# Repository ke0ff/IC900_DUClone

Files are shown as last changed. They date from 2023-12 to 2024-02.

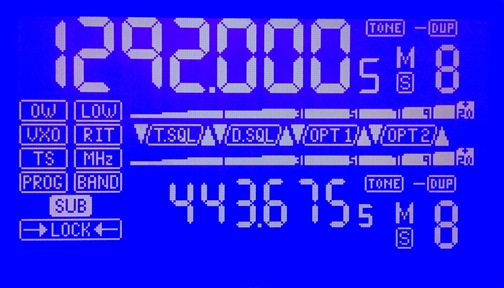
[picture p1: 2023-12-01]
Early_Mockup.JPG

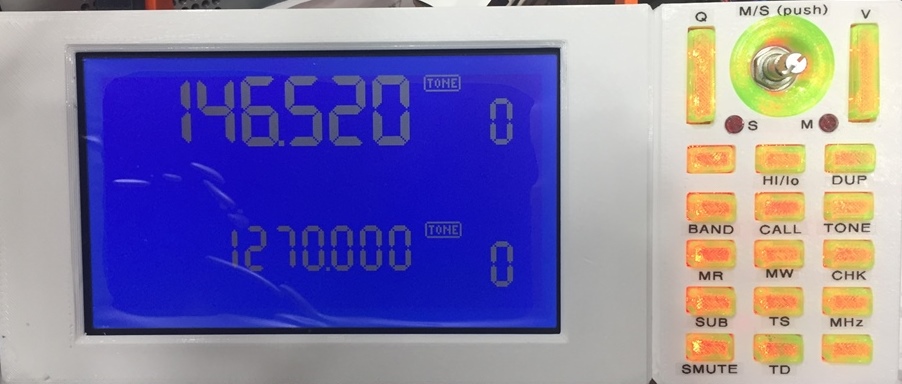
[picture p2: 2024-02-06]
Snapshots/FF900F_frontview.JPG

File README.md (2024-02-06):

# IC900_DUClone
Display clone to replace the LCD ICs/Glass of the original ICOM IC-900 controller

01/05/24<br>
Current state of SW: Initial IC-900-DUC converter DVT compete.  Declared fit for progress into hardware development.  Design is in C (baremetal).

Current state of HW: In FAB.  PCBs should be in-hand by mid-January, 2024.  Design is in Circuit Studio.  In total, there are 6 PCBs for the RDU clone and MFMIC option:<br>
- IC900-RDU (circa 2020): The original controller clone CCA, Tiva MCU
- IC900-DUC (new): The LCD controller and switch matrix CCA, Tiva MCU.  Also holds the NVRAM mod for the RDU and a power switch circuit
- IC900-DIAL (new): A small pcb that connects the dial encoder and dial back-light LEDs to the DUC CCA (no MCU)
- IC90x_RCU-B2 (circa 2020): The MFMIC CCA for the A-unit up/down de-mux function (ATTINY-816)
- IC900_ACONN (new): Provides connectors for RDU and host PC.  The MFMIC CCA mates to this PCB also.  A single 4-pr cable (CAT5) hard-connects to the IC-900 A-Unit
- HM-133B (circa 2020): This is the wired-remote version of the original HM-133 design.  It only supports the ICOM FM radio 8-pin circular/DIN format and provides a serial connection to the MFMIC/RDU to carry the button press messages back to the RDU controller

The "new" PCBs are contained here as complete data packages (source and FAB data).  The older PCBs are committed as FAB data only.

Electronics: Development prototype uses a Tiva TM4C123G Launchpad and Newhaven Display (Inc.) NHD-240128WG-ATMI-VZ# 240x128 graphics LCD.  Switches and backlighting for nomenclature follow a similar architecture as that of the original IC-900 controller. The final design features jumper-wire connections from the RDU Clone board mated to the DUC PCB.  The arrangement would theoretically support using an original IC900 RDU control board in place of the clone-RDU allowing the new LCD to interface with the original controller.

Mechanical: 3D model in advanced stages, nearing prototype readiness. Still need to work out 3D print strategies to support illuminated nomenclature.  Design is in OpenSCAD.  In-process STL files are now in repo.

The "Snapshots" folder contains some images of the current state of the development.

BOM cost: Current cost data is in the $300 per radio ball-park for components and PCBs (not including any costs associated with 3D printing or multiple freight costs associated with lost or forgotten parts - ACH!!!).

02/05/24<br>
First article is in DVT!!! The main mechanical deviation is that of button nomenclature.  I still don't have a difinitive solution in mind.  Cheesy, label printed lettering is the order of the day.  All else is progressing well, aiming for a first-to-field prototype by the end of the month.

Added UM folder for the user's manual source files.

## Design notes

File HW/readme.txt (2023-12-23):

Hardware design for the IC900 display clone interface
Joe Haas, KE0FF
Initial commit: 12/22/2023

Designs are in Altium Circuit Studio.

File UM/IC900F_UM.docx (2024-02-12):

IC900F Remote Controller User’s Manual

Joe Haas, KE0FF

02/11/24

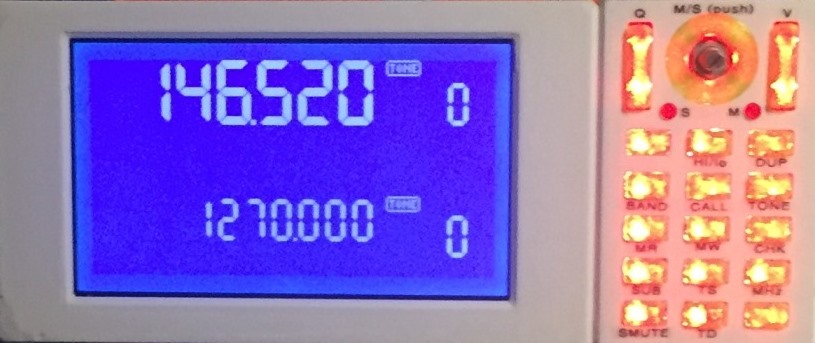
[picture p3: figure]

Introduction

This manual describes the operation of the IC900F, an alternate Remote Controller for the IC900 radio. The mechanical and electrical elements peculiar to the IC900F are also discussed, but for all other aspects of the IC900 radio system, the operator is referred to the IC-900A Instruction Manual, published by ICOM.

Contact information

The author/designer may be contacted at the following email address:

Joe Haas, KE0FF

email: joeh@ke0ff.org

web: www.ke0ff.org

github: https://www.github.com/ke0ff/

Forward

This project was born by an intersection of chance and whimsy to create an alternate controller for the IC-900. Mostly, it serves those who find themselves without such a controller, but in the process, a number of enhancements have been introduced which make the alternate device much more desirable than the original. While some measure of continuity from the original is maintained, new features have blurred that line considerably. Thus, the experienced IC-900 user may find that some considerable “re-learning” is needed to adapt to the new way of doing things.

Such change has not been undertaken lightly. I am a strong supporter of “better” but not so much do I support “newer”. Too many developers like to think that their brand of new is better than the previous version. While I am biased somewhat, I hope that you will agree that most of what I present here as “new” will also be welcomed as “better”.

One aspect that most all should agree is better is that this project is open-source. All of the electrical, software, and 3D models are available via my github repo. Not that that helps much, my source code often baffles even me after I’ve been away from it for a time, but it is the best I can manage given the skills and time I have – this is pursued as a hobby, not a business enterprise. You are free to modify any aspect of the design within the confines of the github license(s). I will assist as best I am able.

It should be noted that the IC-900 “OPT” modules (CTCSS squelch and DTMF coded squelch) are not currently supported. These may come in time, as user demand might influence. For now, they should not be installed.

Connections

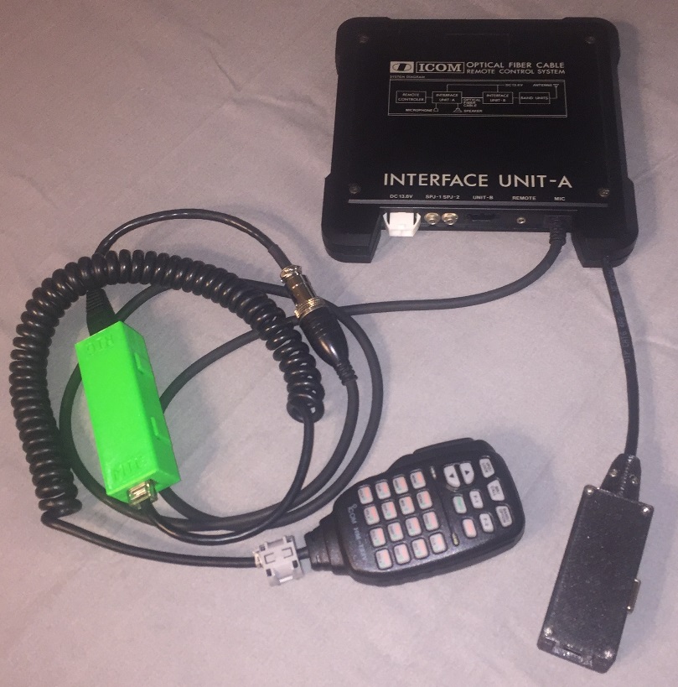
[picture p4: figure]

Figure 1: Modified IC-900 A-Unit and HM-133 Adapter (the controller connection unit is pictured in the lower right of the image)

In order to get the benefit of the HM-133 microphone features, the new controller requires that the A-unit be modified to facilitate the serial connection from the HM-133 to the controller. Figure 1 illustrates a modified A-unit for reference. The hardware to accomplish this also provides an RJ-45 connection for the remote unit. A standard Ethernet cable is recommended so that the signal pairing is correct. Note: The RDU RJ-45 connection is NOT compatible with the HM-133. Care must be exercised to avoid connecting the HM-133 to the RDU connection.

The HM-133 features an adapter cable that connects to the A-unit 8-pin circular connection for the system microphone. A standard, HM-14 (or equivalent) microphone can still be used in place of the HM-133. The connection is seamless and requires no special consideration from the operator.

The controller connection unit features the RJ-45 connection to the Remote Unit and also a 9-pin DSUB connector for a standard COM PORT connection to a PC (115.2 Kbaud, N81). This connection is used to save and restore memory settings for the radio (future enhancements will provide a custom program to perform real-time CAT control of the radio). This interface is describe later in this document.

All other connections are covered in the IC-900 documentation provided by ICOM.

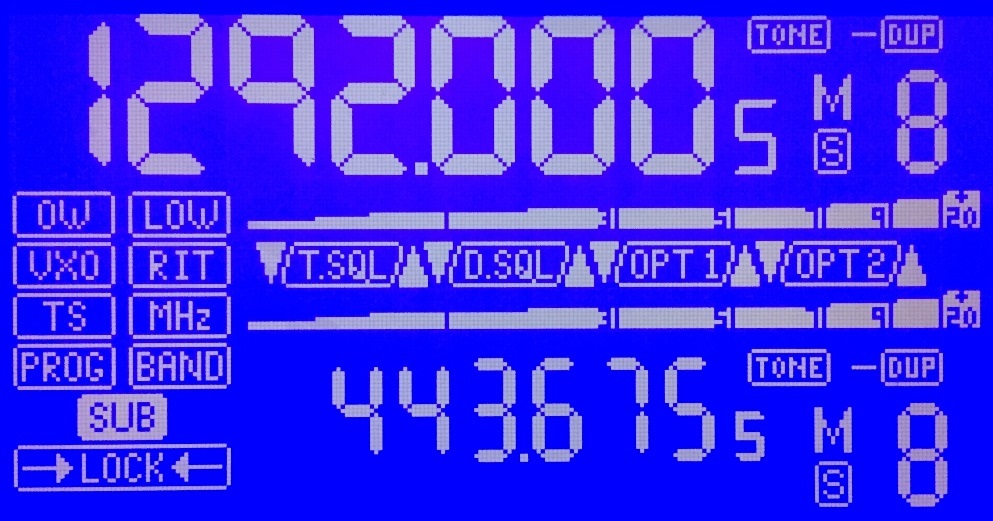
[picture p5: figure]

Figure 2: IC900F display symbol reference

Operation Overview

The IC900F has many similarities with the original IC900 controller. The display format was designed to closely mimic the original IC900 LCD symbology, and the radio maintains the main/sub band approach just as with the original controller. Figure 2 illustrates the display symbology for the IC900F.

The “5” in the 100’s digit of the frequency displays is not utilized as a numeric digit. It flashes to indicate when the CHECK mode is invoked.

The SQL and OPT symbols are not currently used and should not appear in normal operation.

PROG and BAND are not currently used. OW is now FUNC and is used to indicate when the HM-133 FUNC mode is active.

The volume and squelch controls utilize the S-meter tapes to display the setting when it is adjusted. However, the memory channel is employed to display fine-steps in these adjustments:

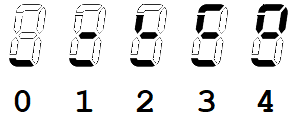
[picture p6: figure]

As the squelch or volume is adjusted up or down, the above patterns convey the fine-step status of those adjustments. These symbols persist only as long as the S-meter tapes are indicating the adjustment setting.

7-Segment Alpha-Numeric Font

This font is used to convey messages in the frequency area and also to indicate memory channels above “9”. Frequency messages can provide up to 6 characters at a time, but a scrolling feature allows up to 16 characters to be displayed. Apart from some system messages, this feature can display memory “names”. These are descriptive strings of text (up to 16 characters) that describe the memory in a human-readable format (the MHz key pressed in MEM mode toggles the display of these messages). These messages are not currently programmable from the IC900F controls, they must be managed off line and uploaded from a PC.

While the font depicted above is generally easily read by the average person, there are some characters that require explanation. These are K, M, U, V, and W. As can be seen from the font map, these characters are somewhat cryptic. They represent the best compromise to create an alphabet with limited segments. In addition, “X” is represented by an upper-case “H”, and “H” is represented as a lower-case “h”. It should be noted that there is no concept of “case” in this font. Upper and lower case characters are employed as needed to achieve maximum clarity. The “opposing” case for any given character is not used even if an easily distinguished pattern is possible in 7-segments.

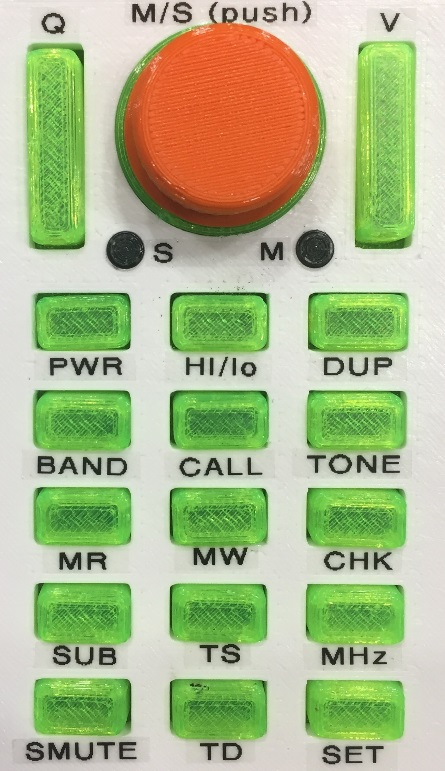
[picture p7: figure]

Control Button Layouts

Figure 3: IC900F Button Layout

The control buttons for the IC900F follow a similar layout to those of the original. Figure 3 illustrates the front panel buttons and dial. Most of the buttons retain their original nomenclature, but there are a couple of exceptions: VFO is now called BAND, and the LOCK and DIM slide switches are replaced by a single push button located at the side of the unit.

From top to bottom:

Q: Squelch toggle – up increases squelch, down decreases. Push-hold increases or decreases to the limit.

Dial: CW increases display number (mem#, frequency, etc…), CCW decreases. Pushing the dial swaps the main/sub bands.

V: Volume toggle – up increases volume, down decreases. Push-hold down sets the volume to 0.

PWR: Press to turn power on/off.

HI/lo: Toggles RF power setting.

DUP: Cycles through duplex settings (+/-/S). Push-hold invokes duplex offset frequency adjust mode.

BAND: Cycles through available band modules. Note: This button has no effect if 2 or less modules are installed.

CALL: Enters 4-channel call memory loop. Dial or mic up/dn buttons cycle through the 4 available call channels. Press-hold programs the VFO into the current call slot.

TONE: Toggles the CTCSS encode function on/off. Press-hold invokes the tone frequency entry mode.

MR: Memory recall – Toggles between mem and VFO mode. Dial or mic up/dn buttons cycle through the 30 available memory channels.

MW: Press-hold to write the VFO settings to the current memory slot.

CHK: If ±DUP is displayed, this button flips the TX/RX frequencies. Press-hold flips TX/RX and opens the squelch (even if DUP is not displayed).

SUB: Toggles the control focus between the main and sub bands.

TS: Toggles between the “A” and “B” tuning step sizes. Push-hold invokes the step-size select mode which allows one of 3 combinations of step size (in KHz): 5/10, 5/25, or 10/25.

MHz: Toggles the MHz mode on/off. When on, frequency steps are in MHz (dial or mic up/dn buttons). When “MHz” is off, the TS step size is in effect. Press-hold puts the frequency into “thumbwheel mode” (more on this later). The MHz button is used to exit the thumbwheel mode. In mem mode, toggles mem text-name display on/off.

SMUTE: Toggles the sub-band speaker mute. Press-hold mutes both main and sub bands. The frequency digits flash for the muted band(s).

TD: no-op. This button is not currently used.

SET: Used to toggle to next memory bank (0 – 9).

DIM/LOCK (located on the side of the unit): Press-release toggles the LED and LCD back-light brightness. Press-hold invokes the LOCK mode which locks the buttons and mic controls. Press-hold releases the LOCK mode.

HM-133 Key Layouts

In addition to duplicating some of the front panel button features, the HM-133 interface provides an extra set of features not available with the existing controller buttons. Figure 4 shows the HM-133 keypad with a description of the key functions to follow. Note: Many of the HM-133 key functions do not match the key nomenclature.

The HM-133 features a FUNC key that is used to modify the key mapping. The descriptions below note the status of the FUNC modifier when it changes the effect of a key. Note: The DTMF key is not used. If pressed accidentally, simply press it again to deactivate the status LED indication. The descriptions below list the HM-133 nomenclature followed by the IC900F function name. Functions that have the same name as the front panel buttons perform in exactly the same way as described for the front panel.

When the FUNC mode is active, the “FUNC” annunciator is illuminated on the LCD (next to the LOW annunciator). Note: The FUNC mode is active after the first press of an active FUNC function, not when the FUNC button is first pressed.

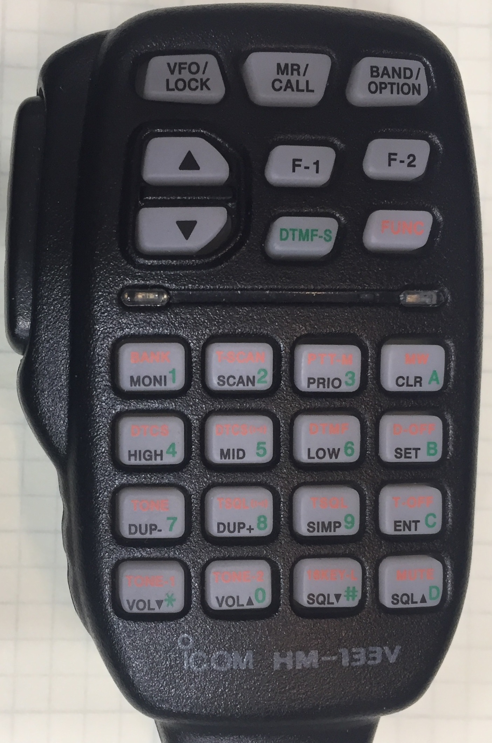
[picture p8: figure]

Figure 4: HM-133 Key layout

From top to bottom (FUNC key modifier INACTIVE):

VFO/LOCK: MHz

MR/CALL: CALL

BAND/OPTION: M/S swap

UP arrow: UP button

F-1: MR

F-2: HI/LO

DN arrow: DN button

DTMF-S: not used

FUNC: FUNC (key shift)

PTT ACTIVE:

Lower 16 keys correspond to the standard DTMF layout and transmit DTMF tones when pressed

PTT Inactive:

Digits 0-9: Direct frequency entry

*: direct freq entry abort

#: Direct freq accept (enter) -or-

CHECK if no DFE operation is in progress

A: TONE

B: SUB

C: BAND

D: SMUTE

Figure 5: HM-133 Key layout (repeated for reference)

From top to bottom (FUNC key mode active):

VFO/LOCK: MHz

MR/CALL: CALL

BAND/OPTION: M/S swap

UP arrow: UP button

F-1: MR

F-2: HI/LO

DN arrow: DN button

DTMF-S: not used

FUNC: FUNC (key shift)

PTT ACTIVE:

Lower 16 keys correspond to the standard DTMF layout and transmit DTMF tones when pressed

PTT Inactive:

1: Backlight increase

2: n/a

3: SQL increase

A: VOL increase

4: Backlight decrease

5: n/a

6: SQL decrease

B: VOL decrease

7: -DUP

8: +DUP

9: S

C: PTTsub interrogate

*: TS

0: n/a

#: n/a

D: PTTsub mode cycle

Press-release vs. Press-hold

The IC900F software can differentiate press-release and press-hold actions on all of the key/button entry points. Many buttons respond to both, while some respond to only one or neither. Generally, an initial press will generate a “beep” at the beep/alert speaker (a piezoelectric speaker mounted inside the controller) if the button is supported. Holding the button pressed for longer than approximately 1 second constitutes a “press-hold” and one or more additional beeps will be issued by the alert speaker (again, if the hold feature is supported for that button). Note: Buttons that have no function associated with press-release or press-hold will not issue any beep acknowledgment.

PTTsub mode

The PTTsub mode is a feature that allows the operator to modify the radio behavior between transmit and receive operations. The “problem” to be solved by this feature was expressed when operating in full-duplex with a sub-band receive path. In this scenario, it was desired to hear the sub-band when transmitting, but mute the sub band when receiving. From this origin, a more complex set of options was devised.

Note: This feature can only be configured via the HM-133 interface. The LCD frequency display will show the status of the mode as a scrolling text message when the HM-133 keys are activated.

PTTsub: OFF

The IC900F behaves just like the IC900 and most all other dual-band radios, it does nothing in particular to the SUB or main band frequency selections in response to TX or RX transitions other than what the DUP setting dictates.

PTTsub: SMUTE

The IC900F toggles the sub-band mute status when transmitting. Depending on how the operator sets the SMUTE manually, this will either mute on TX or un-mute on TX.

PTTsub: MCALL

Swap to the main call channel (the current slot, manually selected) on TX. Returns to previous state (memory or VFO) on RX. If the call channel is selected when pressing PTT, the radio will TX on the VFO/MEM. If VFO/MEM are selected, the IC900F will TX on the CALL channel.

PTTsub: SCALL

Activates the sub call channel (the current slot, manually selected) on TX. Returns the sub-band to previous state (memory or VFO) on RX. In this mode, the TX frequency is determined by the DUP status and behaves as it normally would. The only effect is that the sub-band CALL channel is toggled at the TX/RX transitions.

Backlight Adjust

When adjusting the back-light setting, the adjustment affects the current mode (bright or dim) and is saved in NVRAM so it is retained when the power is cycled.

Thumbwheel Mode

The thumbwheel mode allows the operator to quickly change the operating frequency by adjusting each digit in the frequency value successively, starting at the most significant progressing to the least significant. Press-hold the MHz button (or corresponding HM-133 MHz key) to enter the thumbwheel mode (a double beep signifies the mode has been activated. The most significant (adjustable) digit for the given band will start to flash. The dial or mic U/D buttons will adjust the flashing digit. Once the desired value is displayed, press-release the MHz digit to advance to the next digit to the right (it will start to flash). Once the entire frequency is correct, press-hold MHz to exit the thumbwheel mode. At this point the new frequency is accepted and transferred to the VFO. Note: prior to this “acceptance” the VFO still contains the original frequency. Press-release of the MHz key will continually cycle through the available digits until a press-hold of MHz is initiated. Note: thumbwheel mode only allows frequencies to be selected within the range of the currently selected band.

Direct Frequency Entry

Using the HM-133, it is possible to directly enter the desired VFO frequency. As with the thumbwheel mode, the VFO will retain its original frequency until the new entry is completed. To use this entry mode, ensure that the HM-133 FUNC shift is not activated and PTT is not pressed. Using the HM-133, press the numeric digits for the new frequency starting at the most significant digit proceeding to the 5KHz digit (any digit other than 5 or 0 entered for the 5 Khz position will be rounded to the nearest 5 KHz). The new frequency will appear as it is entered on the display and will “slide to the left” as more digits are entered. If an error is made, press “*” to abort and re-enter. Once the frequency on the display is correct, press “#” to accept the new frequency. Note: The new frequency may be any within the limits of the currently installed band modules – the controller will switch to the new module once the entry is accepted. Frequencies entered for modules not installed will be ignored.

Table 1 illustrates the operating limits imposed by the current software. Note that these limits allow operation outside current amateur allocations. It is up to the operator to ensure that the IC900F is operated in accordance with all FCC rules and regulations. Generally, the performance of the ICOM modules outside the operating frequency ranges published in the ICOM literature results in very poor performance and is not recommended.

Band | Lower frequency limit | Upper frequency limit | Max offset
10m | 27.000 | 40.000 | 13.000
6m | 45.000 | 60.000 | 15.000
2m | 130.000 | 170.000 | 40.000
220 | 215.000 | 228.000 | 13.000
440 | 420.000 | 470.000 | 50.000
1296 | 1200.000 | 1310.000 | 900.000

Table 1. Frequency vs. Band Limits. All frequencies in MHz.

Serial Communications

The serial communications link to the IC900F is a standard RS-232 serial connection operating at 115.2 Kbaud, no parity, 8 data bits, and one stop bit. The commands are human-readable and may be entered via a terminal emulator if the handshaking is set correctly. A custom PC application has been deployed which simplifies the operation and allows some CAT (Computer Automated Transceiver) control capabilities.

For off-line data maintenance, a small adapter is provided that allows the IC900F to be powered by itself and a PC serial connection established. In this scenario, the handshaking limits are not an issue. This is intended for simple upload/download operations to configure the radio parameters and memories. NOTE: If a direct terminal connection is used, the HM-133 buttons (other than UP/DOWN) will not be recognized as long as the terminal connector is attached to the IC900F.

With the current software release, the only viable interface is to use a PC with a terminal emulator application and a USB RS-232 dongle (unless you are using a PC with a build-in RS-232 COM port) to connect your PC to the IC900F. TerraTerm is recommended as it is known to work with the IC900F command-line interface(follow this link for TerraTerm: https://ttssh2.osdn.jp/)

When executing TerraTerm for the first time, select “Serial” and chose the com port associated with the USB dongle (some trial and error may be required to identify the USB COM port#e). Under “Setup→Serial Port”, set the baud rate to 115200, 8 bit, Parity=none, Stop = 1, Flow control = none, Transmit delay = 1msec/char, 400 msec/line. The COM port may also be selected in this dialog box. Other settings should work well with the defaults.

Using the IC900_MEM_MAP0.xls spreadsheet (available at the github repo: https://github.com/ke0ff/IC900_DUClone/tree/main/UM) edit the desired memories making sure to use all upper case characters for the STRING field.When finished, copy and paste the “command line (output) fields that were modified into a text file and save the file to convenient location on the PC hard drive. Note: Unused memories may be deleted from the file to reduce upload time.

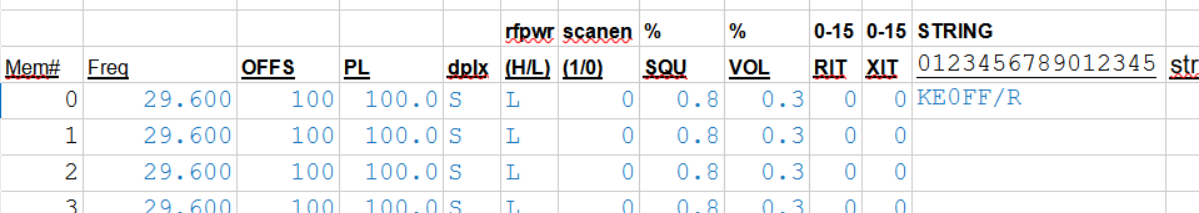
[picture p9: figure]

Figure 6: Memory management spreadsheet excerpt

To upload the memories, confirm that the IC900F is connected to TerraTerm by pressing the “?” key followed by <ENTER>. You should see several lines of help screen text. In TerraTerm, go to “File→ Send file…” and select the text file saved from the spreadsheet output. The contents of the file should be visible as they are sent to the IC900F. This process is rather slow and can take a couple of minutes to send the entire memory space. Watch for “error” results in the terminal window.

Consistent errors during file transfer may indicate a problem with the output data. Occasional errors may indicate that the delay timings are not high enough. Under “Setup→Serial Port”, increase the msec/line value (in increments of 50). If the errors persist beyond 500 msec/line, there may an issue with the spreadsheet or the data entry (the spreadsheet is supposed to provide error checking, but this has not been exhaustively tested).

The memory data is stored in non-volatile memory and no other actions are necessary. Disconnect the serial connection when finished uploading the memory data.

11 DRAFT RELEASE 02-11-24

1 DRAFT RELEASE 02-11-24

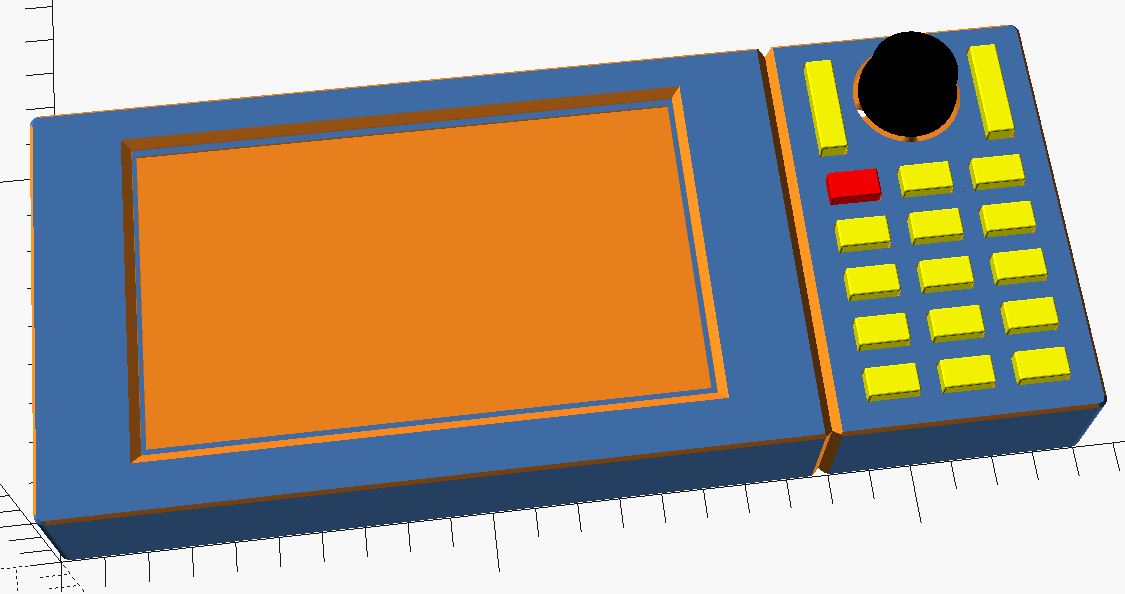
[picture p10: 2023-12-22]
Snapshots/Case_w_buttons.JPG

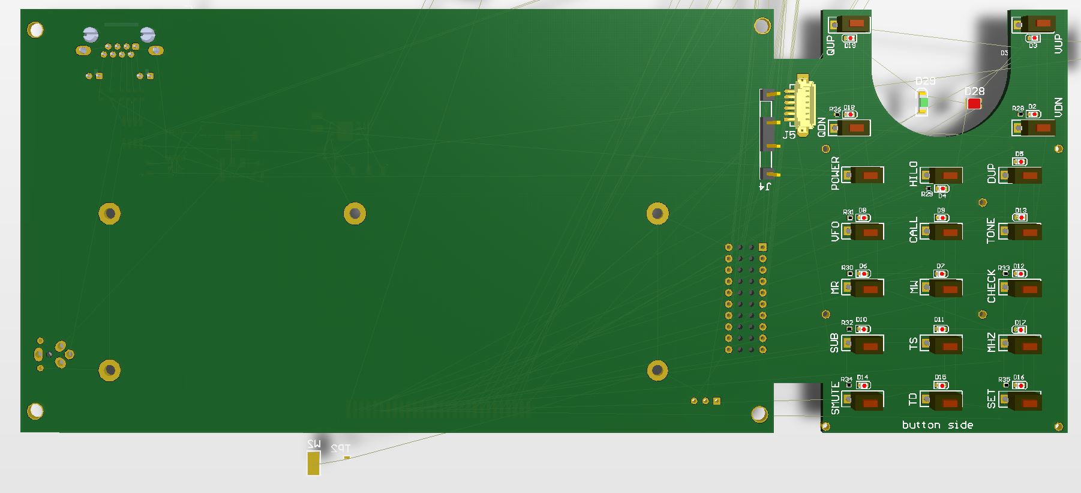
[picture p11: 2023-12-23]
Snapshots/pcb_top.JPG

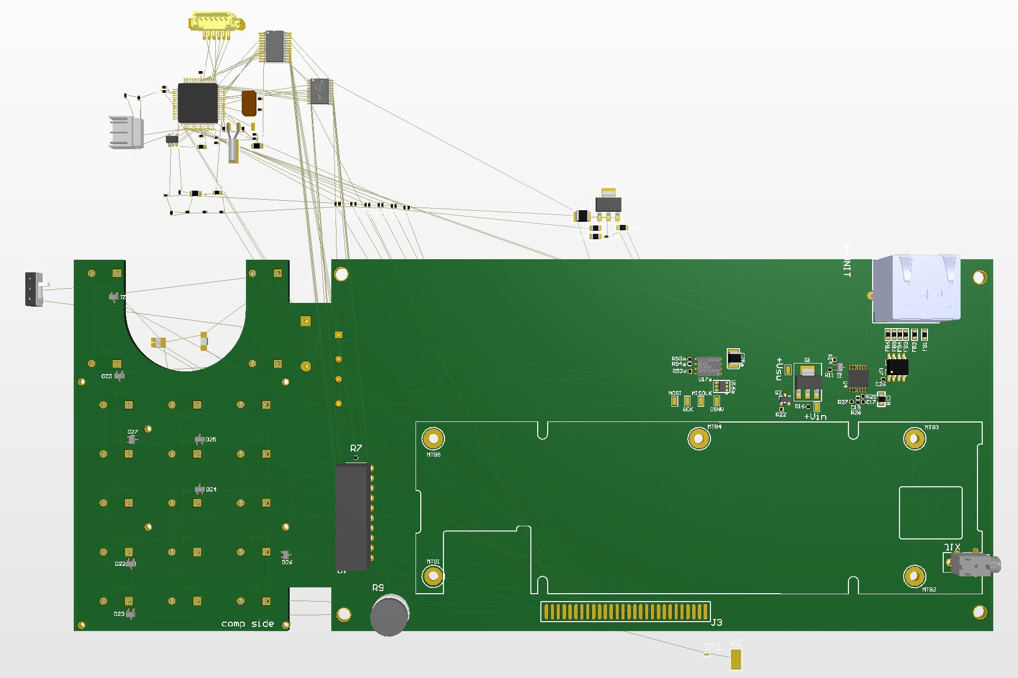
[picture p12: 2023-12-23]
Snapshots/pcb_bot.JPG

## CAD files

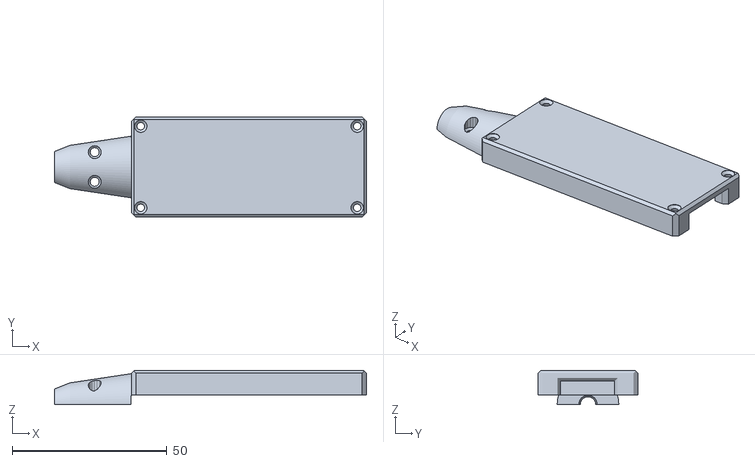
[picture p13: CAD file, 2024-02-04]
3D/stl/IC901F_aunit_top.stl
100.9 x 32.4 x 11.0

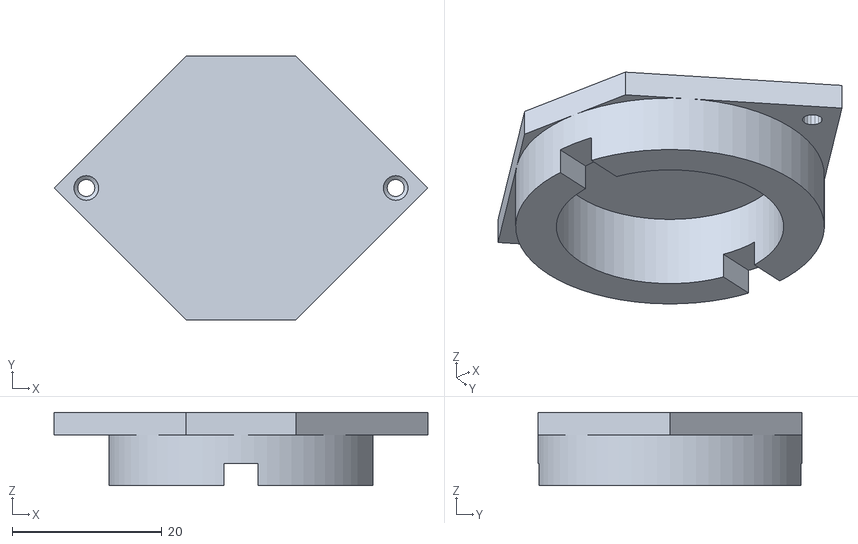
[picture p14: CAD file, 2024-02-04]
3D/stl/IC901F_piezo.stl
49.9 x 35.3 x 9.79

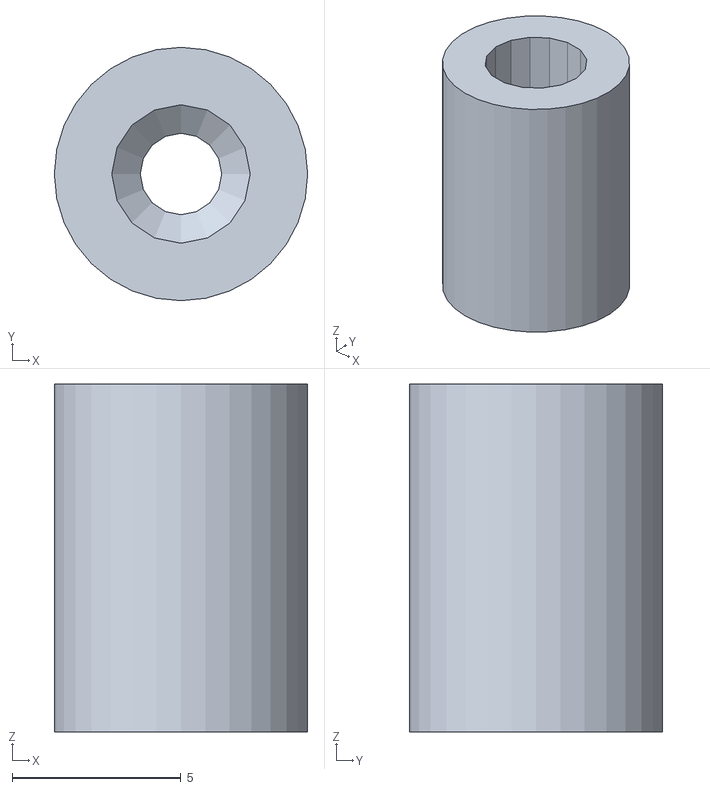
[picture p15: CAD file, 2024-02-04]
3D/stl/IC901F_aunit_spacer.stl
7.50 x 7.50 x 10.3

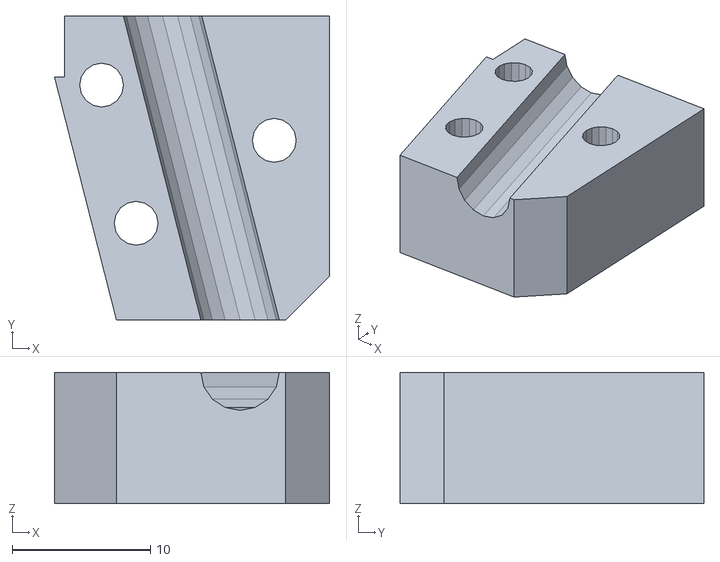
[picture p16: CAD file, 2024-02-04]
3D/stl/IC901F_aunit_clampb.stl
19.9 x 22.0 x 9.50

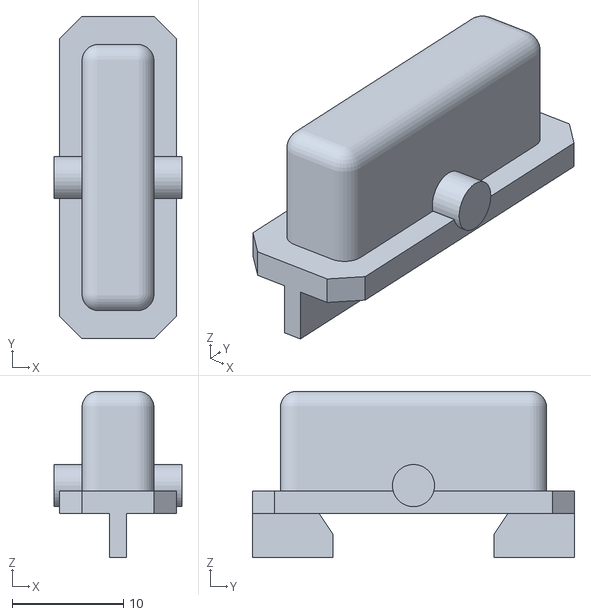
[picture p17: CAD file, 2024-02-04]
3D/stl/IC901F_vqcap.stl
11.5 x 29.0 x 15.0

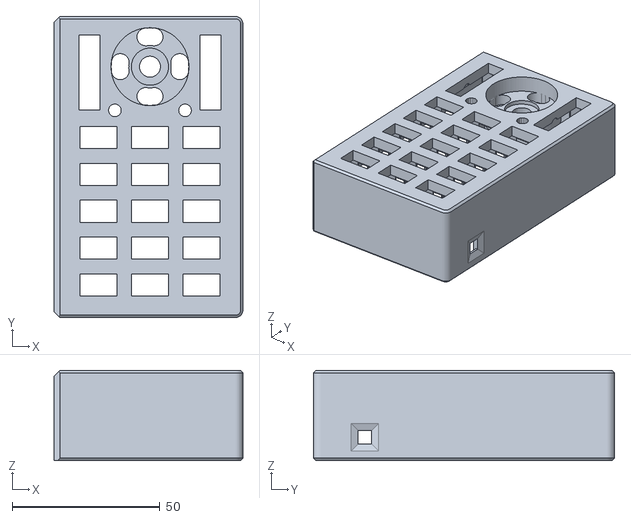
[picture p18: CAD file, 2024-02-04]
3D/stl/IC901F_side2.stl
64.0 x 102.0 x 30.5

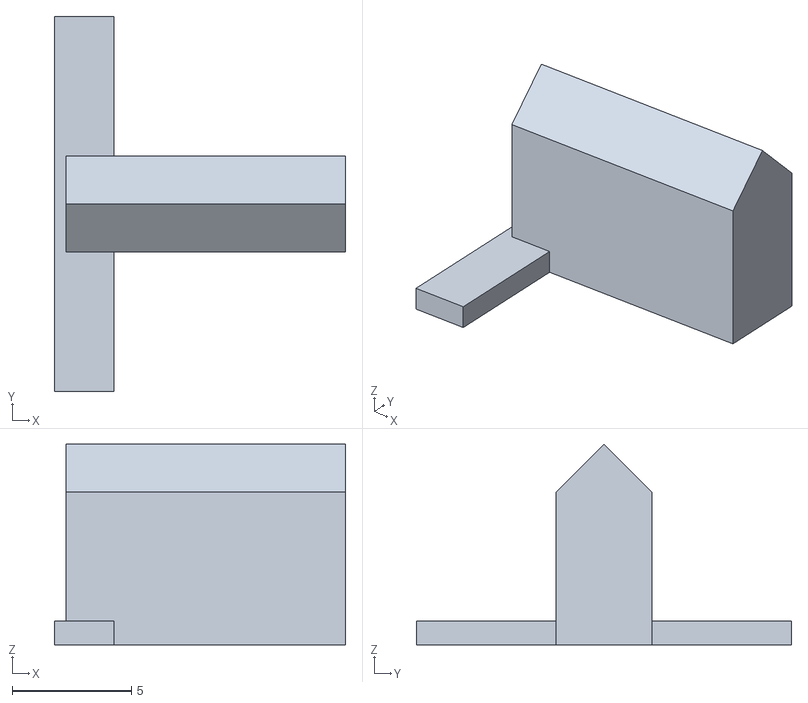
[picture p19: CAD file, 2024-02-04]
3D/stl/IC901F_vqpivot.stl
12.2 x 15.7 x 8.40

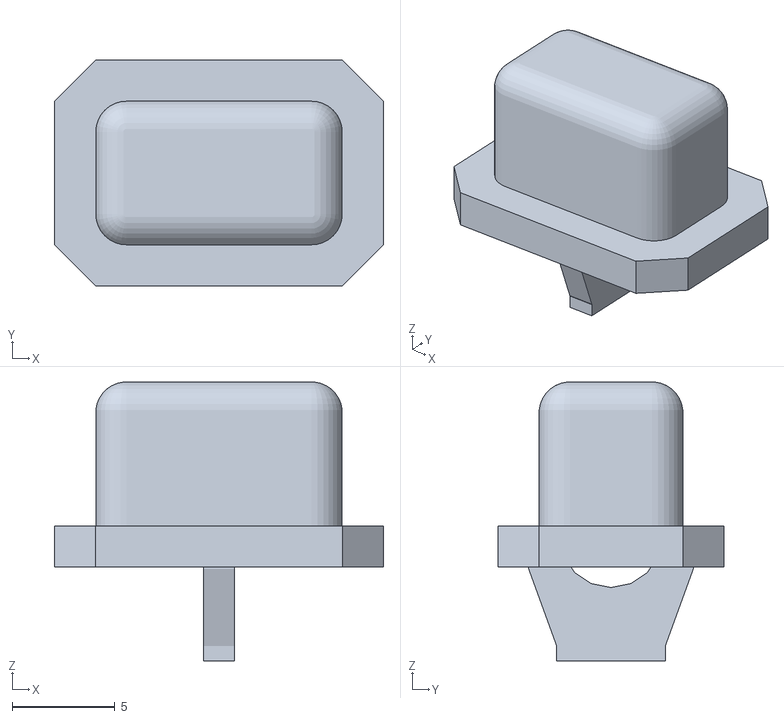
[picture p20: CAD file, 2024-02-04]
3D/stl/IC901F_bcap.stl
16.0 x 11.0 x 13.6

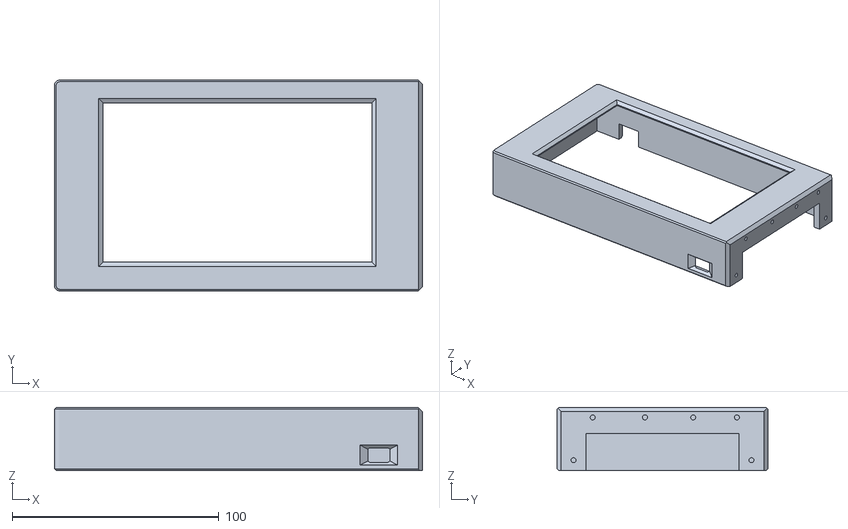
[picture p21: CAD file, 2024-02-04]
3D/stl/IC901F_side1.stl
178.0 x 102.0 x 30.5

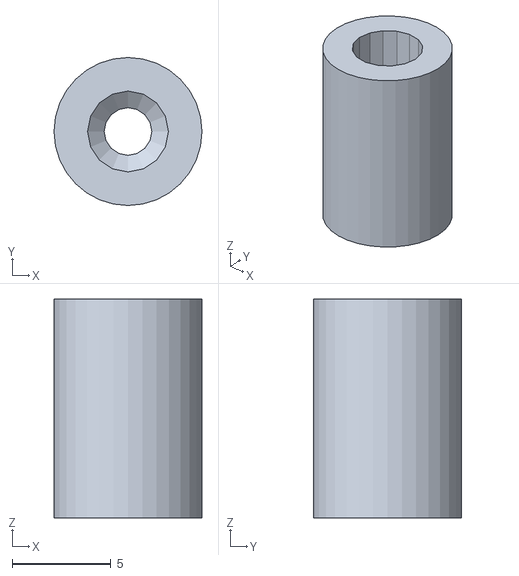
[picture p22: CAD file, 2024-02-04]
3D/stl/IC901F_aunit_spacer2.stl
7.50 x 7.50 x 11.1

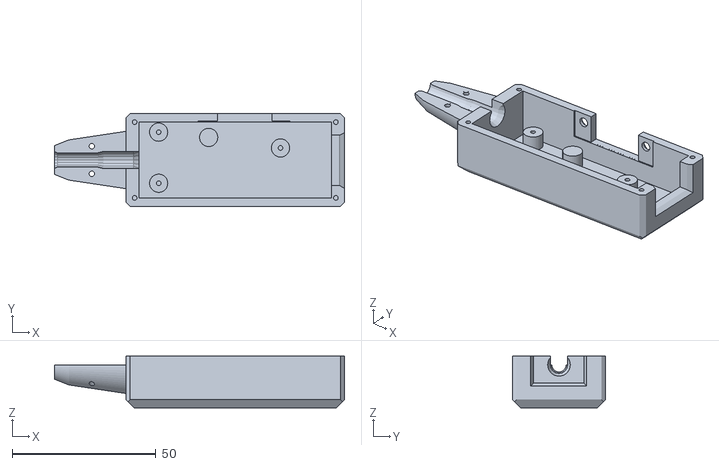
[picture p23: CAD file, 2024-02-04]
3D/stl/IC901F_aunit_bot.stl
100.9 x 32.4 x 18.0

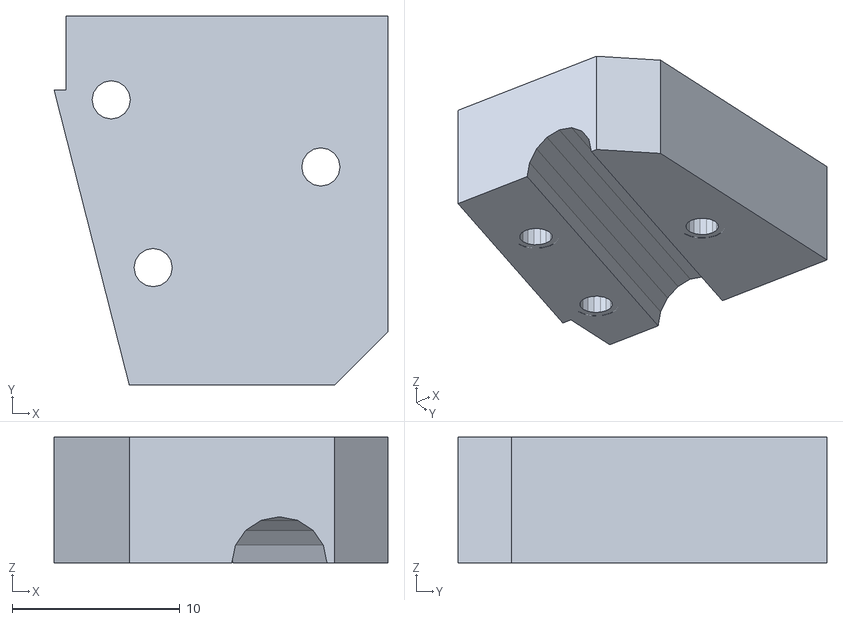
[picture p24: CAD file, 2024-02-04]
3D/stl/IC901F_aunit_clampt.stl
19.9 x 22.0 x 7.50

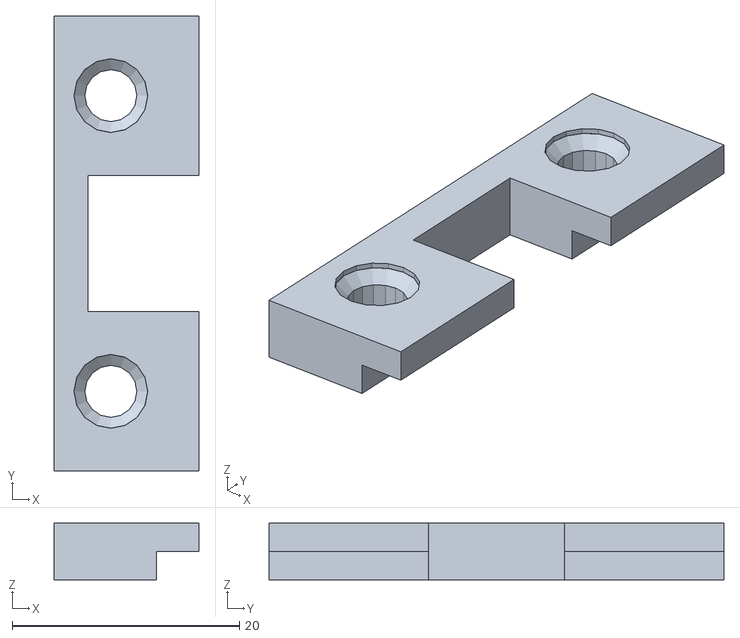
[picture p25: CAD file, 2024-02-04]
3D/stl/IC901F_clip.stl
12.8 x 40.0 x 5.00

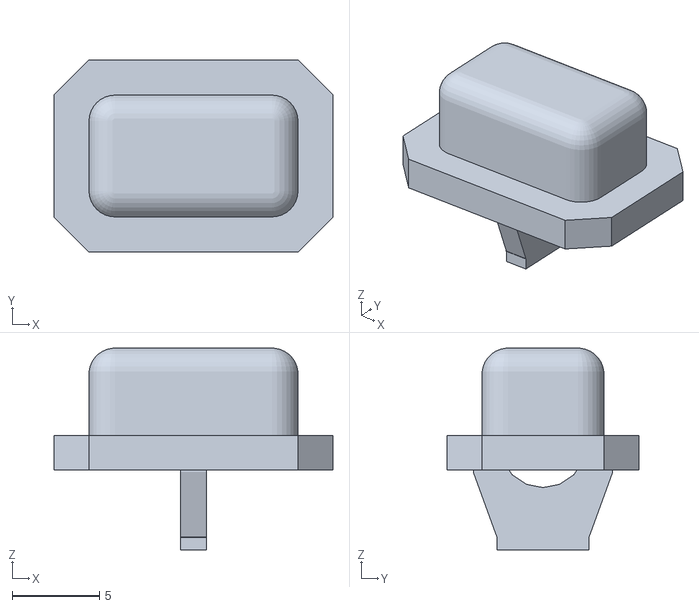
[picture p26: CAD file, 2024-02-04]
3D/stl/IC901F_bcappwr.stl
16.0 x 11.0 x 11.6

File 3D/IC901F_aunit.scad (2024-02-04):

// OpenSCAD 2019.05
// LCD Case - enclosure, REV-001
// Joe Haas, KE0FF, 1/1/2024
// This is the IC900 controller clone A-Unit enclosure
//	This houses the RJ-45 and DSUB-9 and MFMIC pcbs
//
// Rev-001, 1/1/2024
//	initial code

////////////////////////////////////////////////////////////////////////////////
// plot directives.  Enable/disable plot features:
		
button = 0;			// button caps, 1 = normal, 2 = short (power)
vqbtn = 1;			// v/q button
sidesel = 0;		// main case, 1 = lcd side, 2 = button side, 3 = both
backsel = 0;		// back cover, 1 = lcd side, 2 = button side, 3 = both
dopcb = 0;			// display PCB for fit-check
doeclip = 0;		// back-side clip piece
dopiezo = 0;		// piezo cover
dordu = 0;			// RDU PCB for fit-check

////////////////////////////////////////////////////////////////////////////////

//----------------------------------------------------------------------------------------------------------------------
// User defined parameters.  Modify these to suit a particular application
// NOTE: All data in this file is in mm
//----------------------------------------------------------------------------------------------------------------------
// parametric variables:

in2mm = 25.4;

rj45x = .625 * in2mm;
rj45y = .65 * in2mm;
rj45z = .53 * in2mm;
clr = 0.5;
ds9x = 1.22 * in2mm;
ds9y = .49 * in2mm;
ds9z = .49 * in2mm;
ds9ox = .75 * in2mm;
ds9oy = .22 * in2mm;
ds9oz = .49 * in2mm;
ds9mtgx = .99 * in2mm;
ds9mtgz = .99 * in2mm;

sipx = 23;
sipy = 2.5;
sipz = 11;

wally = 3;
wall = 3;
zwall = 2;
cham = 2;
bcham = 4;
tcham = 1.25;

pcb_x = (2.6 * in2mm);
pcb_y = (1 * in2mm);
pcb_z = rj45z + 5;
pcbthk = 1.6;

pcb2_x = 52;
pcb2_y = 20.5;
pcb2_z = 4;
pcb2thk = .8;

box_x = pcb_x+1 + (2*wall)+3;
box_y = pcb_y+1 + (2*wally);
box_z = rj45z + 0.5 + 4;

threadia = 0.065 * in2mm;
dia2 = .095*in2mm;
mtgdia = 0.125 * in2mm;
jackdia = 5.9;
jackwall = 1;
bosdia = .25*in2mm;
hddia = 4.1;
hdht = hddia/2;

topthk = 8;
cbldia = 5;
cbldia2 = 6;


///////////////////////////////////////////////////////////////////////////////
// plot directive processing //////////////////////////////////////////////////

bottom_on = 0;
top_on = 1;
clamp_top = 0;
clamp_bot = 0;

if(bottom_on){
	difference(){
		bottom();
//		translate([-15,30,-10]) cube([200,30,100]);	// debug section
	}
}

if(top_on){
	difference(){
		translate([0,0,box_z+.1]) top();
//		translate([-15,20,-10]) cube([200,100,100]);	// debug section
	}
}

if(clamp_top){
	difference(){
		translate([0,0,0]) clamp(top=1);
//		translate([-15,20,-10]) cube([200,100,100]);	// debug section
	}
}

if(clamp_bot){
	difference(){
		translate([0,0,0]) clamp(top=0);
//		translate([-15,20,-10]) cube([200,100,100]);	// debug section
	}
}

// TEST PRINTS ////////////////
//translate([wall+(.1*in2mm)+.5+1.5,wall+.5,zwall+1+4]) pcb(model=1);

//cable();
//screw();

//csink();

// corner spacer for a-unit PCB
//spacer();

////////////////////////////////////////////////////////////////////////////////////
module bottom(){

	translate([.1,box_y/2,box_z-(cbldia2/2)]) cable(top=0);
	difference(){
		union(){
			difference(){
				cube([box_x, box_y, box_z]);
				translate([wall+1.5,wall,zwall]) cube([pcb_x+1,pcb_y+1,pcb_z]);
				// corner chams
				rotate([0,0,45]) cube([cham,cham,3*box_z], center=true);
				translate([box_x,0,0]) rotate([0,0,45]) cube([cham,cham,3*box_z], center=true);
				translate([0,box_y,0]) rotate([0,0,45]) cube([cham,cham,3*box_z], center=true);
				translate([box_x,box_y,0]) rotate([0,0,45]) cube([cham,cham,3*box_z], center=true);
				// bottom chams
				rotate([45,0,0]) cube([3*box_x,bcham,bcham], center=true);
				translate([0,box_y,0]) rotate([45,0,0]) cube([3*box_x,bcham,bcham], center=true);
				rotate([0,45,0]) cube([bcham,3*box_y,bcham], center=true);
				translate([box_x,0,0]) rotate([0,45,0]) cube([bcham,3*box_y,bcham], center=true);
			}
			// mtg bosses
			translate([wall+(.1*in2mm)+.5+1.5,wall+.5,-.1]){
				translate([.15*in2mm,(.15*in2mm)+.8,zwall]) cylinder(r=bosdia/2, h=5, $fn=32);
				translate([.15*in2mm,(.85*in2mm)+.8,zwall]) cylinder(r=bosdia/2, h=5, $fn=32);
				translate([1.820*in2mm,(0.606*in2mm)+1.5,zwall]) cylinder(r=bosdia/2, h=5, $fn=32);
				translate([.836*in2mm,(0.606*in2mm)+(bosdia/2)+2,zwall]) cylinder(r=bosdia/2, h=5, $fn=32);
			}
		}
		// cable opening
		translate([0,box_y/2,box_z-(cbldia2/2)]) cable(top=0, model=0);
		translate([0,box_y/2,box_z]) cube([20,cbldia2,cbldia2],center=true);
		// pcb features
		translate([wall+(.1*in2mm)+.5+1.5,wall+.5,zwall+1+4]) pcb(model=0, depth=5.95);
		translate([0,0,box_z]) top(model=0);
	}
}

module top(model=1){
mtgoffs = 3;

	if(model==0){
		// mtg holes
		translate([(wall+mtgoffs)/2,wall,0]) cylinder(r=threadia/2, h=20, $fn=16, center=true);
		translate([(wall+mtgoffs)/2,box_y-wall,0]) cylinder(r=threadia/2, h=20, $fn=16, center=true);
		translate([box_x-((wall+mtgoffs)/2),wall,0]) cylinder(r=threadia/2, h=20, $fn=16, center=true);
		translate([box_x-((wall+mtgoffs)/2),box_y-wall,0]) cylinder(r=threadia/2, h=20, $fn=16, center=true);

	}else{
		difference(){
			union(){
				translate([0,0,0]) cube([box_x, box_y, topthk]);
				translate([.1,box_y/2,-(cbldia2/2)]) cable(top=1);
			}
			// cable skirt trim
			translate([-.1,0,-box_z/2-.01]) cube([10,box_y,box_z/2]);
			// inside hog-out
			translate([wall+1.5,wally,-.1]) cube([pcb_x+1,pcb_y+1,topthk-2+.2]);
			// corner chams
			rotate([0,0,45]) cube([cham,cham,3*box_z], center=true);
			translate([box_x,0,0]) rotate([0,0,45]) cube([cham,cham,3*box_z], center=true);
			translate([0,box_y,0]) rotate([0,0,45]) cube([cham,cham,3*box_z], center=true);
			translate([box_x,box_y,0]) rotate([0,0,45]) cube([cham,cham,3*box_z], center=true);
			// top chams
			translate([0,0,topthk]) rotate([45,0,0]) cube([3*box_x,tcham,tcham], center=true);
			translate([0,box_y,topthk]) rotate([45,0,0]) cube([3*box_x,tcham,tcham], center=true);
			translate([0,0,topthk]) rotate([0,45,0]) cube([tcham,3*box_y,tcham], center=true);
			translate([box_x,0,topthk]) rotate([0,45,0]) cube([tcham,3*box_y,tcham], center=true);
			// csinks
			translate([(wall+mtgoffs)/2,wall,topthk-1.1]) csink();
			translate([(wall+mtgoffs)/2,box_y-wall,topthk-1.1]) csink();
			translate([box_x-((wall+mtgoffs)/2),wall,topthk-1.1]) csink();
			translate([box_x-((wall+mtgoffs)/2),box_y-wall,topthk-1.1]) csink();
			// mtg holes
			translate([(wall+mtgoffs)/2,wall,0]) cylinder(r=dia2/2, h=15, $fn=16, center=true);
			translate([(wall+mtgoffs)/2,box_y-wall,0]) cylinder(r=dia2/2, h=15, $fn=16, center=true);
			translate([box_x-((wall+mtgoffs)/2),wall,0]) cylinder(r=dia2/2, h=15, $fn=16, center=true);
			translate([box_x-((wall+mtgoffs)/2),box_y-wall,0]) cylinder(r=dia2/2, h=15, $fn=16, center=true);
			// pcb features
			translate([wall+(.1*in2mm)+.5+1.5,wall+.5,zwall+1+4-box_z]) pcb(model=0, depth=2.95);
		}
	}
}


module clamp(top=0){
	difference(){
		// main body
		cube([20,22,(9.5*2)-2]);
		// corner cham
		translate([4.6,-.1,-5]) rotate([0,0,104.3]) cube([40,20,9.5*3]);
		// cable tunnel
		translate([4.6+8.8+1.4,-5,9.5]) rotate([0,0,14.3]) rotate([-90,0,0]) cylinder(r=5.5/2, h=40, $fn=16);
		// mtg holes
		translate([16,13,9.5]) rotate([180,0,0]) screw(csdeep=9.5, thread=4, sink=0);
		translate([3.5,17,9.5]) rotate([180,0,0]) screw(csdeep=9.5, thread=4, sink=0);
		translate([6,7,9.5]) rotate([180,0,0]) screw(csdeep=9.5, thread=4, sink=0);
		// far-notch
		translate([-.1,22.1-4.5,-5]) cube([.9,4.5,30]);
		// near-cham
		translate([20,0,0]) rotate([0,0,45]) cube([4.5,4.5,45],center=true);
		// top/bottom section
		if(top){
			translate([-1,-1,9.5]) cube([30,30,20]);
		}else{
			translate([-1,-1,-20+9.5]) cube([30,30,20]);
		}
	}
}

//////////////////////////////////////////////////////////////////////////////////////////////////////////////////////////

module csink(){

	cylinder(r2=hddia/2, r1=0, h=hdht, $fn=16, center=true);
	translate([0,0,(hdht/2)-.01]) cylinder(r=hddia/2, h=10, $fn=16);

}

module spacer(){
//	translate([0,0,-4.8-1.6])cube([3,3,12.5]);
	difference(){
		cylinder(r=7.5/2, h=11.1, $fn=32);
		translate([0,0,12.5-4.8-1.6-(hdht/2)]) csink();
		translate([0,0,0]) cylinder(r=dia2/2, h=15, $fn=16, center=true);
//		cube([10,10,20]);
	}
}


module cable(top=0, model=1){
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

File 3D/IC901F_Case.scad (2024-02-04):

// OpenSCAD 2019.05
// LCD Case - enclosure, REV-001
// Joe Haas, KE0FF, 10/19/2023
// This is the IC900 controller clone enclosure which uses an NHD-240128WG LCD module
//	and custom button PCB
//
// Rev-001, 12/25/2023
//	initial code
////////////////////////////////////////////////////////////////////////////////

//----------------------------------------------------------------------------------------------------------------------
// User defined parameters.  Modify these to suit a particular application
// NOTE: All data in this file is in mm
//----------------------------------------------------------------------------------------------------------------------
// parametric variables:

// LCD screen panel thickness
scrnthk = 0.08*25.4;

// hole expansion to compensate 3D print overage
dskew = 0.3;
// interface PCB
pcbz = 14.3-scrnthk+.6;
pcbthk = 1.6;
// LCD mtg hole baselines
lbx = 4+162;
lbdx = 6.38 * 25.4;
lby = (95-4.5-1.5)-85;
lbdy = 3.35 * 25.4;

wthick = 3.5;
wthickt = 1.5;

bswid = 57;
bslen = 95;
bsoffs = 49;
bsoffsy = 41;

bsz = 30;
splitwid = 171 + (2*wthick);
width = 171 + (4*wthick)+bswid;
height = 14+13 + (wthickt) +2;
length = 95 + (2*wthick);
fht_in = 30;					// front inside depth
bheight = wthick;

bossht = 7.8;
crad = 5;
crad2 = crad/2;
chamfer = .8;
lcdz = height-14+4.5; //13+4.5;
scham = 4;

num1_thru = (.09*25.4);
num1_thrd = (.05*25.4)+.3;

// buttons
bwid = 7;				// y
blen = 12;				// x
bht = 6;				// z
bclr = .5;				// clearance
bapron = 2;				// apron clearance around periphery of button base
capron = bapron;		// raw apron around periphery of button base
bapht = 2;				// apron thickness
bnib = 2+.6;			// nib thickness
bcham = 3;				// corner radius
bsep = 1.5;
bpitchx = blen+bsep+(2*bapron);
bpitchy = bwid+bsep+(2*bapron);
bqwid = 25;				// y
bqlen = 6.5;			// x
brelief = 3;			// button protrusion
brocker = 1;			// rocker button lengthwise relief

dialr = (6.5)/2;		// dial thread rad
dialnutr = 12.6/2;		// dial nut
nthick = 2.5;			// dial mounting surface thickness
opvoidr = 25.4/2;
opv_deep = 4;			// sets depth of dial optical void
dial_deep = 10;			// vertical placement of dial mounting plane
shaft_len = 20;			// dial shaft length

hole1 = .06*25.4;

capronx = blen+(2*(bapron+bclr));
caprony = bwid+(2*(bapron+bclr));
capcham = 3;
stcham = 2.5;
stht = 6.4+bapht+.6+.6;

piezx = 85;
piezo_dia = 34.8+.5;
piezo_id = 26;
piezo_ht = 8;

// light dome
domex = 3.5+wthick+12.55;
domey = 3.5+wthick+26.44;
domedia = 25.4;

// contrast pot knob
cpotx = 3.5+wthick+149.9;
cpoty = 3.5+wthick+.7;
pknobdia = 14;
pknobht = 6;

echo("cpotx", cpotx);

subrx = 198.6;
subry = 68.2;
trledia = 4.32;				// no larger than 4mm dia here !!! 4.32mm = 11/64 clearance drill (4.366mm)

///////////////////////////////////////////////////////////////////////////////
// plot directive processing //////////////////////////////////////////////////
		
button = 0;			// button caps, 1 = normal, 2 = short (power)
vqbtn = 0;			// v/q button
dopivot = 0;		// v/q pivot wedge
sidesel = 0;		// main case, 1 = lcd side, 2 = button side, 3 = both
backsel = 0;		// back cover, 1 = lcd side, 2 = button side, 3 = both
dopcb = 0;			// display PCB for fit-check
doeclip = 0;		// back-side clip piece
dopiezo = 0;		// piezo cover
dordu = 0;			// RDU PCB for fit-check
dosunwin = 0;		// sunlight window
dopot = 1;			// pot knob

//////////////////////

//mainpcb();

// ruler
//translate([183,22,0]) cylinder(r=3, h=12.3, $fn=8);

if(button==1){
	cap(model=1);
}
if(button==2){
	cap(model=1, capht=4);
}

if(vqbtn){
	vq();
}

if(sidesel){
	caset(side=sidesel);
}

if(dopcb){
	difference(){
		mainpcb();
//		translate([175,-10,-10]) cube([200,150, 40]);		// debug section
	}
}
//pbsw();


if(dordu){
	rdu();
}

if(doeclip){
	edgeclip();
}

if((backsel==1)||(backsel==3)){
	difference(){
		back1();
//		translate([82,-10,-10]) cube([200,150, 40]);		// debug section
	}
}

if((backsel==2)||(backsel==3)){
	back2();
}


if(dopiezo){
	translate([piezx,77,2*wthick]) rotate([180,0,0]) piezo(model = 1, depth=3*wthick, film = 1);
}

if(dopivot){
	pivot();
}

if(dosunwin){
	sunwin();
}

if(dopot){
	cpknob(model=1);
}

///////////////////////////////////////////////////////////////////////////////

// test instantiations

//deskstand();

// spacer
//cube([3.2,6,4]);

//translate([cpotx,cpoty,pcbz]) cpknob(model = 1);

		
//translate([105,50,2*wthick]) rotate([180,0,0]) piezo(model = 1, depth=3*wthick, film = 1);

//backlight(model = 0);

//hdr20(model=0);

//translate([3.5,3.5,lcdz-scrnthk-.6])
//lcdpcb();


//translate([width-(bsoffs)+bpitchx,length-17,height-dial_deep]) dial(model=1);

//spilot();
//translate([width-(bsoffs),length-bsoffsy,height]) cap(model=1);
//translate([width-(bsoffs)-3,length-19,height]) vq(model=1);

//lcd();
//lid();

//bcaps();

//dial();
//translate([210,12,15.25]) cylinder(r1=2, r2=0, h=12, $fn=16);

// ruler
//translate([160,0,13.4-5.4]) cylinder(r=4, h=17.1+5.4, $fn=16);

////////////////////////////////////////////////////////////////////////////////////
module mainpcb(mode=0){

pgmz = .2*25.4;
jlcdz = 8.9;
rj45z = 13.2;

	translate([10-5.8,3.5,pcbz]){
		if(mode==0){
		// RJ45 test fit
//			translate([0,0,-(13.5)]) cube([10,10,13.5]);
		}
		// pgm conn
		color("white") translate([116,63,-pgmz]) cube([7.4,14.6,pgmz]);
		// lcd conn
		color("brown") translate([164.5-3.5,22.5-4.2,-jlcdz]) cube([7.4,23.1,jlcdz]);
		// rj45 conn
		color("white") translate([14.25,77.8,-rj45z]) cube([15.8,15.8,rj45z]);

		difference(){
			// pcb substrate
			color("green")cube([160+74,94.5,1.6]);
			translate([width-(bsoffs)+bpitchx-4.2,length-17-3.5,-10]) cylinder(r=31/2, h=30, $fn=64, center=false);
			translate([width-(bsoffs)+bpitchx-4.2,length-17-3.5+(31/2),0]) cube([31,31,10],center=true);
			translate([174,4,0]) cube([11,17,10],center=true);
			translate([174,92,0]) cube([11,17,10],center=true);
			// 20p header
			translate([170-5.8-.7,18.5,0]) hdr20(model=0);
			// backlight -
			translate([170-2.7-.7,58,0]) backlight(model=0);
			translate([-.7,0,0]) lcd(mtg=true);
			if(mode==0){
				translate([-10+5.8,-3.5,-10.95-14.3]){
					// button spacers
					translate([width-(bsoffs),length-bsoffsy,height]) pbsw(model=mode);
					translate([width-(bsoffs)+bpitchx,length-bsoffsy,height]) pbsw(model=mode);
					translate([width-(bsoffs)+(2*bpitchx),length-bsoffsy,height]) pbsw(model=mode);
					
					translate([width-(bsoffs),length-bsoffsy-bpitchy,height]) pbsw(model=mode);
					translate([width-(bsoffs)+bpitchx,length-bsoffsy-bpitchy,height]) pbsw(model=mode);
					translate([width-(bsoffs)+(2*bpitchx),length-bsoffsy-bpitchy,height]) pbsw(model=mode);
					
					translate([width-(bsoffs),length-bsoffsy-(2*bpitchy),height]) pbsw(model=mode);
					translate([width-(bsoffs)+bpitchx,length-bsoffsy-(2*bpitchy),height]) pbsw(model=mode);
					translate([width-(bsoffs)+(2*bpitchx),length-bsoffsy-(2*bpitchy),height]) pbsw(model=mode);
					
					translate([width-(bsoffs),length-bsoffsy-(3*bpitchy),height]) pbsw(model=mode);
					translate([width-(bsoffs)+bpitchx,length-bsoffsy-(3*bpitchy),height]) pbsw(model=mode);
					translate([width-(bsoffs)+(2*bpitchx),length-bsoffsy-(3*bpitchy),height]) pbsw(model=mode);
					
					translate([width-(bsoffs),length-bsoffsy-(4*bpitchy),height]) pbsw(model=mode);
					translate([width-(bsoffs)+bpitchx,length-bsoffsy-(4*bpitchy),height]) pbsw(model=mode);
					translate([width-(bsoffs)+(2*bpitchx),length-bsoffsy-(4*bpitchy),height]) pbsw(model=mode);
				
					// v/q toggles
					bqswoffs = (bqwid/2)-1;
					translate([width-(bsoffs)-3,length-19-bqswoffs,height]) pbsw(model=mode);
					translate([width-(bsoffs)-3,length-19+bqswoffs,height]) pbsw(model=mode);
					translate([width-11,length-19-bqswoffs,height]) pbsw(model=mode);
					translate([width-11,length-19+bqswoffs,height]) pbsw(model=mode);
				}
			}
			// spacer screw holes
			translate([width-(bsoffs)-4.2,length-bsoffsy-3.5,15]) cap(model=12);
	//		translate([width-(bsoffs)-4.2,length-bsoffsy-3.5,15]) cap(model=13);
			
			translate([width-(bsoffs)+(2*bpitchx)-4.2,length-bsoffsy-3.5,15]) cap(model=10);
			translate([width-(bsoffs)+(2*bpitchx)-4.2,length-bsoffsy-3.5,15]) cap(model=13);
	
			translate([width-(bsoffs)-4.2,length-bsoffsy-(2*bpitchy)-3.5,15]) cap(model=10);
	
//			translate([width-(bsoffs)-4.2,length-bsoffsy-(2*bpitchy)-3.5,15]) cap(model=12);
			translate([width-(bsoffs)+(2*bpitchx)-4.2,length-bsoffsy-(2*bpitchy)-3.5,15]) cap(model=10);	
			translate([width-(bsoffs)+(2*bpitchx)-4.2,length-bsoffsy-(4*bpitchy)-3.5,15]) cap(model=11);
	
			translate([width-(bsoffs)-4.2,length-bsoffsy-(4*bpitchy)-3.5,15]) cap(model=10);
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

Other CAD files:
3D/stl/IC901F_back2.stl
3D/stl/IC901F_sundome.stl
3D/stl/IC901F_back1.stl
3D/stl/IC901F_dialwin.stl
3D/char.scad
3D/stl/IC900F_back3.stl
3D/stl/IC900F_bcap.stl
3D/stl/IC900F_pcb.stl
3D/stl/IC900F_side1.stl
3D/stl/IC900F_side2.stl
3D/stl/IC900F_side3.stl
3D/stl/IC900F_spacer.stl
3D/stl/IC900F_vqcap.stl
3D/stl/IC901F_pot.stl
3D/stl/LCDpcb.stl
3D/stl/button.stl

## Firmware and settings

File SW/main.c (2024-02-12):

/********************************************************************
 ************ COPYRIGHT (c) 2023 by ke0ff, Taylor, TX   *************
 *
 *  File name: main.c
 *
 *  Module:    Control
 *
 *  Summary:
 *  This is the main code file for the IC-900 DU/LCD Clone application.
 *
 *******************************************************************/

/********************************************************************
 *  Project scope rev notes:
 *  !! The TI datasheet lies !! UART: configuring 2 stop bits requires 2 stop bits for RX also
 *
 *  Summary
 *  This project produces an LCD display that is form-fit-function interchangeable with the LCD system used
 *  on the IC-900 Remote Controller.  The Tiva captures SPI messages from the host to the uPD7225 LCD interface
 *  ICs (two are used for the IC-900), interprets the commands/data, and uses them to drive graphic patterns
 *  on a dot-matrix LCD display.
 *
 *  The LCD used here is a 240x128, parallel bus, monochrome display offered by NewHaven, P/N NHD-240128WG-ATMI-VZ#
 *
 *    Project scope rev History:
 *    In-process code-n-test.
 *<V0.1>
 *    02-11-24:		changed "OW" symbol to inverse "FUNC"
 *    				Code stability = 8.5.  Release to field test -jhaas
 *<V0.0>
 *    12-17-23:		SPI TO error now places a hash of horzontal lines on the display to accentuate the stale data.
 *    				Fixed trig2 processing bug.  Now there are no errors in the IC-900 DVT.
 *
 *    12-16-23:		Lots of debug and hair-pulling.  Finally stumbled on correct handling of the dmem/bmem and trigger
 *						system.  Since the IC-900 constantly sends data, the SW must focus on detailed bit changes in
 *    					dmem and bmem to calculate the correct trigger process so that the constant updates do not
 *						interfere with the blink process.  This now seems to be working on the original IC-900 controller.
 *						Need to try it on the RDU clone next.
 *					Added overflow and ssi timeout error flags.  Overflow flag persists, TO flag will clear if comms
 *						are restored.
 *					Added comments and cleaned up debug hacks.
 *    12-08-23:		Added blink code to process_LCD().  Includes refresh of original segments when blink mem is written
 *    					(allows system to recover the original symbol when the blink segment is "unblinked").
 *    					Trapped BLINKOFF SPI cmd to re-trigger any blinking segments.
 *    				Some preliminary SSI RX testing: The way to get an ISR hit for every byte received is to use the RX timeout
 *    					feature (this basically bypasses the FIFO).  This requires the SSI clock to be set to a value that will
 *						give a favorable result.  32 SSI clocks are required for the timeout.  So, the SSI clock needs to be
 *						set to 1/(32*(tword+tclearance)). tword is the minimum time between SSI bytes and tclearance is the
 *						overhead time needed to service the SSI ISR before the next SSI word starts.  The RTIM mask bit needs
 *						to be set, and the timeout needs to be cleared manually inside the SSI ISR.
 *						FSS does not seem to be used by the SSI as a slave.  Only the SCLK and data seem to be needed.
 *    12-07-23:		Ran a full segment unit test from a simulated SPI stream capture to LCD display.  Debugged
 *    					a couple of issues to get the CS1 and CS2 paths functional and all segments tested/verified.
 *    12-06-23:		Added CMD/DATA gpio to capture status of this "address" signal by SPI.
 *    				Preliminary unit test of SPI buffer data flow to LCD display was successful (after some debug).
 *	  12-04-23		Pieces are coming together.  Got basic LCD ram->display mechanism working.  Starting to add
 *						SPI stuff. Need to code LCD commands and work out the processing of the the SPI buffer.
 *					Added process_SPI with most of a dispatch switch to process SPI cmds/data (need a scrub and DVT run)
 *
 *    11-21-23 jmh:  creation date
 *    				 <VERSION 0.0>
 *
 *******************************************************************/

//-----------------------------------------------------------------------------
// main.c
//  Interfaces IC-900 LCD SPI interface to a dot-matrix LCD
//  UART0 is used for debug I/O.
//
//  Debug CLI is a simple maintenance/debug port (via UART1 @PB[1:0]) with the following core commands:
//		? - help
//		VERS - interrogate SW version
//		LT - LCD Test cmd
//		See "cmd_fn.c" for CLI details
//
//	Uses GPIO to drive LCD 8-bit bus I/O
//
//	GPIO edge ISR inputs LCD bbSSI data (RX only)
//
//	GPIO is used for the LCD parallel interface.  PB = bi-directional 8-bit port, PE = interface lines for 8b port,
//		and 2 GPIOs on port D to drive mode signals to the LCD.
//
//  Interrupt Resource Map:
//	*	Timer3A			--			app timer
//	*	-deprecated- SSI0			PA2/4:		LCD interface ICs (uPD7225) SPI
//	*	GPIOA			PA2:		LCD interface ICs (uPD7225) bit-bang SSI (allows consistent capture of CS and CMD/DATA meta data)
//	*	UART0 			PA[1:0]:	ISR(RX/TX) debug serial port
//	*	-notused- M1PWM (4)		PF1:		LED PWM to drive LCD backlight
//		ADC0			PD2:		Ambient light sensor
//
//
//  I/O Resource Map:
//      See "init.h"
//
//-----------------------------------------------------------------------------

//-----------------------------------------------------------------------------
// Includes
//-----------------------------------------------------------------------------
// compile defines

#define MAIN_C
#include <stdint.h>
#include "inc/tm4c123gh6pm.h"
#include <stdio.h>
#include <string.h>
#include "init.h"
#include "typedef.h"
#include "version.h"
#include "serial.h"
#include "cmd_fn.h"
#include "tiva_init.h"
#include "eeprom.h"
#include "lcd_db.h"
//#include "radio.h"
#include "uxpll.h"
#include "spi.h"

//-----------------------------------------------------------------------------
// Definitions
//-----------------------------------------------------------------------------

//  see init.h for main #defines
#define	MAX_REBUF	4		// max # of rebufs
#define	MAX_BARS	7		// max # of led bars
#define	GETS_INIT	0xff	// gets_tab() static initializer signal
#define DAC_LDAC 20			// dac spi defines
#define DAC_PWRUP 21
#define DAC_CLR 22


//-----------------------------------------------------------------------------
// Local Variables
//-----------------------------------------------------------------------------

// Processor I/O assignments
//bitbands
#define DUT_ON  (*(volatile uint32_t *)(0x40058000 + (0x04 * 4)))
#define DUT_OFF (*(volatile uint32_t *)(0x40058000 + (0x08 * 4)))
#define DUT_SCK (*(volatile uint32_t *)(0x40058000 + (0x10 * 4)))
#define DUT_D   (*(volatile uint32_t *)(0x40058000 + (0x20 * 4)))
#define DUT_Q   (*(volatile uint32_t *)(0x40058000 + (0x40 * 4)))
#define DUT_CS  (*(volatile uint32_t *)(0x40058000 + (0x80 * 4)))

//-----------------------------------------------------------------------------
// Global variables (extern conditionals are in init.h)
//-----------------------------------------------------------------------------
char	bchar;							// break character trap register - traps ESC ascii chars entered at terminal
char	swcmd;							// software command flag
S8		handshake;						// xon/xoff enable
S8		xoffsent;						// xoff sent

//-----------------------------------------------------------------------------
// Local variables in this file
//-----------------------------------------------------------------------------
char	got_cmd;						// first valid cmd flag (freezes baud rate)
U32		abaud;							// 0 = 115.2kb (the default)
U8		iplt2;							// timer2 ipl flag
U16		waittimer;						// gp wait timer
U16		waittimer2;						// gp wait timer
U16		ipl_timer;						// ipl timeout timer
U8		cmdtimer;						// cmd_ln GP timer
U16		blinktimer;						// blink regs
U8		blinkfl;

U32		free_32;						// free-running ms timer
S8		err_led_stat;					// err led status
U8		idx;
U16		ipl;							// initial power on state
char	btbuf[100];						// temp buffer

U8		led_5_on;
U8		led_6_on;
//U8		led_2_level;					// led level regs (0-100%)
//U8		led_3_level;
//U8		led_4_level;
U8		led_5_level;
U8		led_6_level;
//U16		pwm2_reg;						// led pwm regs
//U16		pwm3_reg;
//U16		pwm4_reg;
U16		pwm5_reg;
U16		pwm6_reg;
U8		pwm_master;						// led master level
U8		sw_state;
U8		sw_change;
//char	dbbuf[30];	// debug buffer
//U8		dbug8;
U8		hib_access;						// HIB intrpt lock-out flag

//-----------------------------------------------------------------------------
// Local Prototypes
//-----------------------------------------------------------------------------

void Timer_Init(void);
void Timer_SUBR(void);
char *gets_tab(char *buf, char *save_buf[3], int n);

//*****************************************************************************
// main()
//  The main function runs a forever loop in which the main application operates.
//	Prior to the loop, Main performs system initialization, boot status
//	announcement, and main polling loop.  The loop also calls CLI capture/parse fns.
//	The CLI maintains and processes re-do buffers (4 total) that are accessed by the
//	TAB key.  Allows the last 4 valid command lines to be recalled and executed
//	(after TAB'ing to desired recall command, press ENTER to execute, or ESC to
//	clear command line).
//	Autobaud rate reset allows user to select alternate baudarates after reset:
//		115,200 baud is default.  A CR entered after reset at 57600, 38400,
//		19200, or 9600 baud will reset the system baud rate and prompt for user
//		acceptance.  Once accepted, the baud rate is frozen.  If rejected, baud rate
//		returns to 115200.  The first valid command at the default rate will also
//		freeze the baud rate.  Once frozen, the baud rate can not be changed until
//		system is reset.
//*****************************************************************************
int main(void){
	volatile uint32_t ui32Loop;
//	uint32_t i;
//    uint8_t	tempi;			// tempi
    char	buf[CLI_BUFLEN];	// command line buffer
    char	rebuf0[RE_BUFLEN];	// re-do buffer#1
    char	rebuf1[RE_BUFLEN];	// re-do buffer#2
    char	rebuf2[RE_BUFLEN];	// re-do buffer#3
    char	rebuf3[RE_BUFLEN];	// re-do buffer#4
    U8		argn;				// number of args
    char*	cmd_string;			// CLI processing ptr
    char*	args[ARG_MAX];		// ptr array into CLI args
    char*	rebufN[4];			// pointer array to re-do buffers
    U16		offset;				// srecord offset register
    U16		cur_baud;			// current baud rate
    U8		fault_found;		// fault detected flag

    fault_found = FALSE;								// only trap one fault-restart
	got_cmd = FALSE;
	offset = 0;
	cur_baud = 0;
    iplt2 = 1;											// init timer1
    ipl = proc_init();									// initialize the processor I/O
 	while(iplt2);										// wait for timer to finish intialization
	dispSWvers(); 										// display reset banner
	init_ssi0();
	process_LCD(0xff);
    do{													// outer-loop (do forever, allows soft-restart)
        rebufN[0] = rebuf0;								// init CLI re-buf pointers
    	rebufN[1] = rebuf1;
    	rebufN[2] = rebuf2;
    	rebufN[3] = rebuf3;
    	rebuf0[0] = '\0';								// clear cmd re-do buffers
    	rebuf1[0] = '\0';
    	rebuf2[0] = '\0';
    	rebuf3[0] = '\0';
    	wait(10);										// a bit more delay..
    	while(gotchrQ()) getchrQ();						// clear serial input in case there was some POR garbage
    	gets_tab(buf, rebufN, GETS_INIT);				// initialize gets_tab()
        set_led(0xff, 0x00);							// init LED levels
        set_pwm(0, 99);									// master = 100%
        set_led(5, 1);									// enable LEDs at 10% until the OS takes over
        set_pwm(5, 10);
        set_led(6, 1);
        set_pwm(6, 10);
    	process_IO(PROC_INIT);							// init process_io
    	// GPIO init
    	//...
    	// main loop
        do{
    		putchar0(XON);
    		buf[0] = '\0';
    		putssQ("rdu>");										// prompt
    		cmd_string = gets_tab(buf, rebufN, RE_BUFLEN); 		// get cmd line & save to re-do buf
    		if(!got_cmd){										// if no valid commands since reset, look for baud rate change
    			if(cur_baud != abaud){							// abaud is signal from gets_tab() that indicates a baud rate change
    				if(set_baud(abaud)){						// try to set new baud rate
    					putsQ("");								// move to new line
    					dispSWvers();							// display reset banner & prompt to AKN new baud rate
    					while(gotchrQ()) getchrQ();				// clear out don't care characters
    					putssQ("press <Enter> to accept baud rate change: ");
    					while(!gotchrQ());						// wait for user input
    					putsQ("");								// move to new line
    					if(getchrQ() == '\r'){					// if input = CR
    						cur_baud = abaud;					// update current baud = new baud
    						got_cmd = TRUE;						// freeze baud rate
    					}else{
    						set_baud(0);						// input was not a CR, return to default baud rate
    						cur_baud = abaud = 0;
    					}
    				}else{
    					abaud = cur_baud;						// new baud rate not valid, ignore & keep old rate
    				}
    			}else{
    				got_cmd = TRUE;								// freeze baud rate (@115.2kb)
    			}
    		}
    		argn = parse_args(cmd_string,args);					// parse cmd line
    		if(x_cmdfn(argn, args, &offset)) got_cmd = TRUE;	// process cmd line, set got_cmd if cmd valid
    		if((NVIC_FAULT_STAT_R) && !fault_found){			// test for initial fault
    	        putsQ("nvic FLT\n");							// fault message
    			swcmd = SW_ESC;									// abort to restart
    			fault_found = TRUE;
    		}
        }while(swcmd != SW_ESC);
    }while(1);
}

//-----------------------------------------------------------------------------
// Subroutines
//-----------------------------------------------------------------------------

//-----------------------------------------------------------------------------
// gets_tab puts serial input into buffer, UART0.
//-----------------------------------------------------------------------------
// Main loop for command line input.
// waits for a chr and puts into buf.  If 1st chr = \t, copy re-do buf into
//  cmdbuf and cycle to next re-do buf.  if more than n chrs input, nul term buf,
//	disp "line too long", and return.  if \n or \r, copy buf to save_buf & return
//  returns buf (pointer).
//	if n == 0xff, initialize statics and exit.
//
//	11/08/13: Modified to support 4 (MAX_REBUF) rolling cmd save buffers
//	11/15/13: Modified to support auto-baud detect on CR input
//		For the following, each bit chr shown is one bit time at 115200 baud (8.68056us).
//			s = start bit (0), p = stop bit (1), x = incorrect stop, i = idle (1), bits are ordered  lsb -> msb:
//	 the ascii code for CR = 10110000
//			At 115.2kb, CR = s10110000p = 0x0D
//
//			At 57.6 kb, CR = 00110011110000000011 (1/2 115.2kb)
//			@115.2, this is: s01100111ps00000001i = 0xE6, 0x80
//
//			At 38.4 kb, CR = 000111000111111000000000000111 (1/3 115.2kb)
//			@115.2, this is: s00111000p11111s00000000xxxiii = 0x1c, 0x00
//
//			At 19.2 kb, CR = 000000111111000000111111111111000000000000000000000000111111 (1/6 115.2kb)
//			@115.2, this is: s00000111piis00000111piiiiiiiis00000000xxxxxxxxxxxxxxxiiiiii = 0xE0, 0xE0, 0x00
//
//			At 9600 b,  CR = 000000000000111111111111000000000000111111111111111111111111000000000000000000000000000000000000000000000000111111111111 (1/12 115.2kb)
//			@115.2, this is: s00000000xxxiiiiiiiiiiiis00000000xxxiiiiiiiiiiiiiiiiiiiiiiiis00000000xxxxxxxxxxxxxxxxxxxxxxxxxxxxxxxxxxxxxxxiiiiiiiiiiii = 0x00, 0x00, 0x00
//
//		Thus, @ 57.6 kb, a CR = 0xE6 followed by 0x80
//			  @ 38.4 kb, a CR = 0x1C followed by 0x00
//			  @ 19.2 kb, a CR = 0xE0 followed by 0xE0 (plus a 0x00)
//			  @ 9600 b, a  CR = 0x00 followed by 0x00 (plus a 0x00)
//
//		NOTE: gets_tab is only used for command line input and thus should not
//		see non-ascii data under normal circumstances.
//		re-NOTE: The wired remote sees non-ASCII in the check byte by design.  Need to refurb this code...

char *gets_tab(char *buf, char *save_buf[], int n){
	char	*cp;
	char	*sp;
	char	c;
volatile	char	q = 0;
	int		i = 0;
	U8		j;
	U8		se = 0;						// status enable reflection.  If enabled, suppress echo
	static	U8   rebuf_num;

//	if((rebuf_num >= MAX_REBUF) || (n == GETS_INIT)){ // n == 0xff is static initializer signal
	if(n == GETS_INIT){ // n == 0xff is static initializer signal
		rebuf_num = 0;									// init recall buffer pointer
		return buf;										// skip rest of Fn
	}
    cp = buf;
    sp = save_buf[rebuf_num];
    do{
    	do{
    		// run the process loops and capture UART chars
    		process_IO(0);
    		c = getchQ();
    	}while(!c && !q);
    	if(!q){
            switch(c){
                case '\t':
    				if(i != 0){								// if tab, cycle through saved cmd buffers
    					do{
    						i--;							// update count/point
    						cp--;
    						if((*cp >= ' ') && (*cp <= '~')){
    							if(!se){
        							putchar0('\b');		// erase last chr if it was printable
        							putchar0(' ');
        							putchar0('\b');
        							kickuart0();
    							}
    						}
    					}while(i != 0);
    					cp = buf;							// just in case we got out of synch
    				}
    				//copy saved string up to first nul, \n, or \r
    				j = rebuf_num;
    				do{
    					if(--rebuf_num == 0xff){
    						rebuf_num = MAX_REBUF - 1;
    					}
    					if(*save_buf[rebuf_num]) j = rebuf_num;
    				}while(j != rebuf_num);
    				sp = save_buf[rebuf_num];
    				while((*sp != '\0') && (*sp != '\r') && (*sp != '\n')){
    					putdchQ(*sp);
    					*cp++ = *sp++;
    					i++;
    				}
    				kickuart0();
                    break;

                case '\b':
                case 0x7f:
                    if(i != 0){								// if bs & not start of line,
                        i--;								// update count/point
                        cp--;
                        if((*cp >= ' ') && (*cp <= '~')){
							if(!se){
    							putchar0('\b');			// erase last chr if it was printable
    							putchar0(' ');
    							putchar0('\b');
    							kickuart0();
							}
                        }
                    }
                    break;

                case '\r':									// if cr, nul term buf & exit
                case '\n':									// if nl, nul term buf & exit
                    i++;
                    *cp++ = c;
                    putchar_bQ('\n');						// no cntl chrs here
                    break;

                case ESC:									// if esc, nul buf & exit
                    cp = buf;
                    c = '\r';								// set escape condition
    				i = 0;
    				putchar_bQ('\n');						// no cntl chrs here
                    break;

                case BT_LN:									// if bluetooth cmd, do nothing
                    break;

                default:
                    i++;
                    *cp++ = c;								// put chr in buf
                    if(!se){
                        putdchQ(c);							// no cntl chrs here
                    }
                    break;
            }
    	}
    } while((c != '\r') && (c != '\n') && (i < CLI_BUFLEN) && (c != BT_LN));		// loop until c/r or l/f or buffer full
    if(c != BT_LN){
    	if(i >= CLI_BUFLEN){
    		putsQ("#! buffer overflow !$");
    		*buf = '\0';								// abort line
    	}else{
    		if(!se){
        		putsQ("");								// echo end of line to screen
    		}
    		*cp = '\0';									// terminate command line
    		if((*buf >= ' ') && (*buf <= '~')){			// if new buf not empty (ie, 1st chr = printable),
    			strncpy(save_buf[rebuf_num], buf, n);	// copy new buf to save
    			if(++rebuf_num >= MAX_REBUF) rebuf_num = 0;
    		}
    	}
    }
    return buf;
}

//-----------------------------------------------------------------------------
// process_IO() processes system I/O
//-----------------------------------------------------------------------------
void process_IO(U8 flag){

	// perform periodic process updates					// ! SOUT init must execute before SIN init !
	process_CMD(flag);									// process CMD_FN state (primarily, the MFmic key-entry state machine)
	process_LCD(flag);									// lcd updates and blink machine
	process_SPI(flag);									// spi input processing
	process_ERR(flag);									// error reporting
	return;
}

//-----------------------------------------------------------------------------
// set_pwm() sets the specified PWM to the percent value
//	pwmnum specifies the LED number.  LED 0 is the master setting.  This only sets the master,
//		it does not update any of the LED pwm registers.
//	percent is the percent level, 0 - 100.  If percent > 100, the value is unchanged
//		and the PWM settings are calculated based on stored led and master values
//-----------------------------------------------------------------------------
void set_pwm(U8 pwmnum, U8 percent){
	U32	kk;				// temp U32

	if(percent <= 100){
		switch(pwmnum){						// store level % value
		case 0:								// set master value
			pwm_master = percent;
			break;
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

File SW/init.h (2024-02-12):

/********************************************************************
 ************ COPYRIGHT (c) 2021 by ke0ff, Taylor, TX   *************
 *
 *  File name: init.h
 *
 *  Module:    Control, IC-900 RDU Controller Clone
 *
 *  Summary:   defines and global declarations for main.c
 *  			Also defines GPIO pins, timer constants, and other
 *  			GPIO system constants
 *
 *******************************************************************/

#include "typedef.h"
#include <stdint.h>

#ifndef INIT_H
#define INIT_H
#endif

#define	DEBUG 1
//#define	USE_QSPI 1

//////////////////////////////////////////////////////////////////////////////////////
//#define	USE_QSPI 1																//
//#define	LA_ENABLE				// define if logic analyzer is enabled (debug)	//
//////////////////////////////////////////////////////////////////////////////////////

//////////////////////////////////////////////////////////////////////////////////////
// Pin List
//
//	PB[7:0]:	bidirectional 8b port.  Uses SN74LXC8T245-Q1 (or equiv) bus voltate translator to drive 5V LCD port
//	PA[1:0]:	debug UART
//	PA2:		SCLK		Ersatz (bit-bang) SSI0
//	PA3:		CSS = (/CS1 * /CS2) (74AHC1G08 w/ Vdd=3.3V and inputs dropped to 3.3V with R-divider)
//	PA4:		MOSI
//	PA5:		/CS2		meta data for bbSSI, IC-900 LCD chip2 enable
//	PA6:		/CS1		meta data for bbSSI, IC-900 LCD chip1 enable
//	PA7:		CMDATA		meta data for bbSSI, IC-900 cmd/data enable
//	PD0:		/FS			drives LCD font size input
//	PD1:		/RVS		drives LCD reverse input
//	PE0:		/RSTIN		IC900 LCD reset input
//	PE1:		/TRD		LCD bus control sig, /RD (pin 2 of SN74LXC8T245-Q1)
//	PE2:		/TWR		LCD bus control sig, /WR
//	PE3:		/TADDR		LCD bus control sig, CMD addr bit
//	PE4:		/TCE		LCD bus control sig, /CE (pin 22 of SN74LXC8T245-Q1)
//	PE5:		LRST		LCD reset sig
//	PF4:		SCLKE		-deprecated- alt SCLK for edge capture
//
//	Inputs other than those that use the SN74LXC8T245-Q1 are passed through a resistive divider to convert 5V to 3.3V.
//	Rseries = 523 ohms, Rshunt = 1K ohm.  Outputs use 74AHCT gates to convert 3.3V to 5V.  /FS, /RVS, & LRST use NFETs
//	with pullups to 5V.
//
// LCD Pin List
//		/--- 500K ---\
//	CaseGND	 1	2   GND
//		+5V	 3	4   Vbias (arm of 10K pot.  PotH goes to pin 9, PotL goes to GND)
//		/WR	 5	6   /RD
//		/CE	 7	8   TADDR
//		-Vo	 9	10  /reset
//		D0	11	12  D1			D[7:0] connects to PB[7:0] via a voltage xlator IC
//		D2	13	14  D3			!!!- The prototype has the even and odd bits transposed, so there is a #if in "lcd_db.h"
//		D4	15	16  D5			!!!  to fix this (SWAPEVEN is the #if define)
//		D6	17	18  D7
//		FS	11	12  RVS
//
//////////////////////////////////////////////////////////////////////////////////////
//-----------------------------------------------------------------------------
// Global Constants
//-----------------------------------------------------------------------------

#define SYSCLKL 10000L
#define PIOCLK	(16000000L)			// internal osc freq (in Hz)
#define EXTXTAL           			// un-comment if external xtal is used
									// define EXTXTAL #def to select ext crystal
									// do not define for int osc
#ifdef EXTXTAL
#define XTAL 1
//#define XTAL_FREQ	SYSCTL_RCC_XTAL_16MHZ	// set value of external XTAL
#define XTAL_FREQ	SYSCTL_RCC_XTAL_20MHZ	// set value of external XTAL
#define SYSCLK	(80000000L)					// sysclk freq (bus clk)
//#define SYSCLK	(66667000L)				// sysclk freq (bus clk)
#else
#define XTAL 0
#define SYSCLK	PIOCLK						// sysclk freq (bus clk) same as PIOCLK
#endif

#define OSC_LF 4            				// osc clock selects
#define OSC_HF 0
#define OSC_EXT 1

// process_xx() defines
#define	PROC_INIT	0xff					// IPL command for process calls

#define	MS_PER_TIC	1
#define SEC10MS    (10/MS_PER_TIC)          // timer constants (ms)
#define SEC33MS    (33/MS_PER_TIC)
#define SEC50MS    (50/MS_PER_TIC)
#define SEC75MS    (74/MS_PER_TIC)
#define SEC100MS  (100/MS_PER_TIC)
#define SEC250MS  (250/MS_PER_TIC)
#define SEC300MS  (300/MS_PER_TIC)
#define SEC400MS  (400/MS_PER_TIC)
#define SEC500MS  (500/MS_PER_TIC)
#define SEC750MS  (750/MS_PER_TIC)
#define SEC1     (1000/MS_PER_TIC)
#define ONESEC   SEC1
#define MS1500   (1500/MS_PER_TIC)
#define SEC2     (2000/MS_PER_TIC)
#define SEC3     (3000/MS_PER_TIC)
#define SEC5     (5000/MS_PER_TIC)
#define SEC10   (10000/MS_PER_TIC)
#define SEC15   (15000/MS_PER_TIC)
#define SEC30   (30000/MS_PER_TIC)
#define SEC60   (60000/MS_PER_TIC)
#define SEC300 (300000L/MS_PER_TIC)
#define	ONEMIN	(SEC60)
#define	REG_WAIT_DLY 		200				// 200ms wait limit for register action
#define RESP_SAMP 			SEC100MS		// sets resp rate
#define	SOUT_PACE_TIME		9				// 33/4800 s for one SOUT msg
#define	SIN_PACE_TIME		50				// wait a little over 2 word times (2 x 32/4800 s for one SIN word)
#define	CLI_BUFLEN	100						// CLI buffer length
#define	RE_BUFLEN	40						// buffer mem lengths
#define	BLINK_TIME	SEC250MS				// blink cycle time

// prescaled timer constants
#define	PS_PER_TIC	10
#define	PRESCALE_TRIGGER (PS_PER_TIC)		// establishes 10ms/lsb prescaled timer rate
#define PSEC10MS    (10/PS_PER_TIC)
#define	PSEC33MS    (33/PS_PER_TIC)
#define	PSEC50MS    (50/PS_PER_TIC)
#define	PSEC75MS    (74/PS_PER_TIC)
#define	PSEC100MS  (100/PS_PER_TIC)
#define	PSEC250MS  (250/PS_PER_TIC)
#define	PSEC300MS  (300/PS_PER_TIC)
#define	PSEC400MS  (400/PS_PER_TIC)
#define	PSEC500MS  (500/PS_PER_TIC)
#define	PSEC750MS  (750/PS_PER_TIC)
#define	PSEC1     (1000/PS_PER_TIC)
#define	PSEC2     (2000/PS_PER_TIC)
#define	PSEC3     (3000/PS_PER_TIC)
#define	PSEC5     (5000/PS_PER_TIC)
#define	PSEC10   (10000/PS_PER_TIC)
#define	PSEC15   (15000/PS_PER_TIC)
#define	PSEC30   (30000/PS_PER_TIC)
#define	PSEC60   (60000/PS_PER_TIC)
#define	PSEC300 (300000L/PS_PER_TIC)

#define	CLEAR_TIMER		0xff				// timer control Fn signals
#define	READ_TIMER		0x00
#define	SET_TIMER		0x01
#define	CATA_TIME		PSEC2				// CAT activity rate
#define	CATO_TIME		PSEC10				// CAT timeout rate
#define	CATZ_TIME		SEC50MS				// CAT pacing timer rate

// ssi bit rate defns
// BR = SYSCLK/(CPSR * (1 + SCR))
// SCR = (SYSCLK/(BR * CPSR)) - 1
// see SSICLK_calc.xls for minimum error values for CPSDVSR and SCR
// 4800 baud for SSI1
#define	SIO_BAUD		4800L				// IC900 serial I/O baud rate
#define	SSI1_BR			SIO_BAUD			// ssi1 clock rate (Hz)
#define SSI1_CPSDVSR	(248)
#define	SSI1_SCR		(41)				//((SYSCLK/(SSI1_BR * SSI1_CPSDVSR)) - 1)
// 100K baud for SSI3
#define	LCD_BAUD		25000L				// LCD serial I/O baud rate
#define	SSI3_BR			LCD_BAUD			// ssi3 clock rate (Hz)
#define SSI3_CPSDVSR	(200)
#define	SSI3_SCR		(2)					//((SYSCLK/(SSI3_BR * SSI3_CPSDVSR)) - 1)

// SIN bit time defines... assumes PS = 0 (SYSCLK/1 is used for timer)
#define TIMER2A_PS 0
#define	SIN_BIT_TIME		(SYSCLK/(SIO_BAUD * (TIMER2A_PS + 1)))		// 10416
#define	SIN_HALF_BIT_TIME	(SIN_BIT_TIME/2)							// 5208
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

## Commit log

2023-11-25 Initial Commit
    Initial commit of the Tiva ARM protocol converter for the IC-900 display replacement clone.
2023-11-28 In-process commit
    All symbols coded and QC'd. Need to clean up write routines to include blank/write option. Then, SPI input and symbol update dispatch.
2023-12-01 In-process commit
    REF/support file for segment mapping and naming
    [RDU seg map.xls]
2023-12-02 12/02/23 IPC
    added function name column and sheet to format the Fn name list into C array syntax
    [RDU seg map.xls]
2023-12-03 12/02/23 IPC
    [RDU seg map.xls]
2023-12-09 12-08-23 IPC
    Blink initial testing is good. Began live SSI testing with a simple byte generator. Now have an SSI that interrupts after each byte is received (need to do some clock tricks and use the RX timeout fe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
2023-12-10 12-09-23 IPC
    SPI debug with IC900 datastream ongoing...
2023-12-11 12-10-23 IPC
    Good news, basic SPI function seems to be good - the on-off segment functions well and the uPD7225 blink function works also. There are problems with how the IC900 controller manages most of it's blink operations that likely will require a complete re-design of how the graphics are managed. This shouldn't be a problem when used with my IC-900 controller clone, so victory is nigh! (neegh!).
    [init.h, lcd_db.c, lcd_db.h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]
2023-12-16 12-16-23 IPC
    LCD response is best ever, but still have issues (e.g., the OP1 arrows blanking in the set loop). Good news. Not great, but good. The segment on/off calculations are WAY more complicated than I had them setting out. Oy.
    [lcd_db.c, spi.c]
2023-12-22 Initial Commit 12-20-23
    These are the hardware and mechanical design source files for the DU Clone project
    [IC901F_Case.scad, char.scad]
2023-12-23 Initial commit
    Snapshot images of the current 3D and PCB development
2023-12-24 IPC 12-23-23
    [IC901F_Case.scad]
2023-12-25 IPC 12-24-23
    [IC901F_Case.scad]
2023-12-25 IPC 12-25-23
    [IC901F_Case.scad]
2023-12-26 IPC 12-25-23 #2
    [IC901F_Case.scad]
2023-12-27 IPC 12-26-2023
    [IC901F_Case.scad]
2023-12-28 IPC 12-27-23
    [IC901F_Case.scad]
2023-12-28 IPC 12-27-23 (the real one)
    [IC901F_Case.scad]
2024-01-01 IPC 12-31-23
    [IC901F_Case.scad]
2024-01-06 Initial commit of current 3D output
    NOT FINAL@ This is just an in-process snapshot. Note: Not all of the required pieces are in this commit.
    [IC900F_back3.stl, IC900F_bcap.stl, IC900F_pcb.stl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]
2024-02-04 IPC 02-03-24
    MARK-I prototype part files
    [IC901F_aunit_bot.stl, IC901F_aunit_clampb.stl, IC901F_aunit_clampt.stl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]
2024-02-04 IPC 02-03-24
    MARK-I prototype source files
    [IC901F_Case.scad, IC901F_aunit.scad]
2024-02-10 IPC 02-09-24
    Added mem management spreadsheet
    [IC900_MEM_MAP0_calc.xls]
2024-02-11 First Draft Release
    Draft rev_0 release of manual (word and pdf format), mem spreadsheet, and mem init data file (initializes all memories in current bank to a known state).
2024-02-12 Release 0.1: 02-11-24
    SW stable, ready for first prototype release
